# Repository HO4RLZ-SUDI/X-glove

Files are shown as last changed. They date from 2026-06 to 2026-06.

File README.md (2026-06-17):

# Glove Project

Smart glove project with Android BLE controls, ESP32 firmware, CAD case files,
and build notes.

## Folder layout

- `apps/android_ble_app` - Kotlin + Jetpack Compose Android app.
- `firmware/esp32_glove_ble` - main ESP32 BLE glove firmware.
- `firmware/esp32_ble_name_server` - BLE name server and OLED status sketch.
- `firmware/tests/oled_i2c_test` - OLED I2C test sketch.
- `hardware/cad` - OpenSCAD, STL, and 3MF case versions.
- `docs/bom_budget.ods` - parts budget and BOM spreadsheet.
- `up.sh` - firmware picker, compile, upload, and serial monitor helper.

## Common commands

List available Arduino sketches:

```bash
./up.sh --list
```

Build and upload firmware:

```bash
./up.sh
```

Build the Android app:

```bash
cd apps/android_ble_app
./gradlew assembleDebug
```

# X-glove

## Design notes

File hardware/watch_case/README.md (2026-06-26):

# Glove wrist unit — watch-style enclosure

A 3D-printable, two-part wrist case for the glove electronics, styled after the
reference `frame.stl` (an Apple-Watch-like squircle: ~43 × 49 mm face, rounded
"pillow" edges, side crown + button). The reference is a solid styling shell —
this is the functional version: hollow, holds the boards, and has a display
window, USB access, and a flex-cable entry.

The body is built as a squircle prism **Minkowski-rounded by a sphere**, so every
outer edge (top, back, vertical corners) is filleted into one smooth pillow like
the reference, while the side walls stay flat and the shell stays a uniform
thickness. The face is a flat, recessed **rounded-rectangle "glass" area** (no
cosmetic round ring) with the OLED window in it — Apple-Watch style.

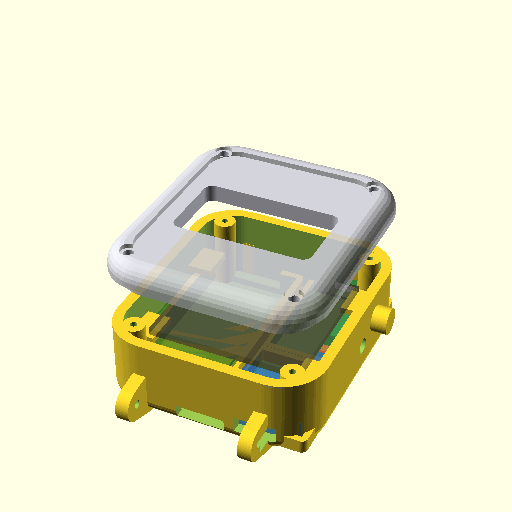
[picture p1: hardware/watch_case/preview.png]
preview


## What it fits

| Part | Size used | Where |
| --- | --- | --- |
| SH1106 1.3" OLED (128×64) | board 35×33, active 29×15.5 | top, behind the window |
| ESP32-C3 SuperMini | 22.5×18×6, USB-C on short end | board slot, +X column −Y end, USB to −Y wall |
| Type-C charge module | TP4056-class 26×17×5, USB-C on short end | board slot, +X column +Y end, USB to +Y wall |
| MPU6050 (GY-521) | 16×21×3 | shelf over the charge module (floor is full; still rigid) |
| LiPo pouch | **20×40×6** | walled compartment on the −X floor, wired to the charge module |
| Flex-divider board | thin perfboard ~22×40×≤2.5 | rests on the battery compartment walls (holds the 5 pull-down resistors) |
| Flex-sensor ribbon | ~11×3 slot | −Y wall centre (palm side) |

Wrist band: **Apple-Watch-style lugs** with a quick-release spring-bar channel
(default 24 mm / 42-45-49 family — see Assembly step 7).

**Power path:** the LiPo is wired to the on-board **Type-C charge module**, so the
case charges through the +Y wall port without opening it; the ESP32's own USB-C
(−Y wall) is then only for flashing. (No `BATTERY_PIN` is free on the C3 — all of
ADC1 goes to the 5 flex channels — so battery % isn't read in firmware.)

The footprint grew from the reference's 43 × 49 mm to **48 × 55 mm** so the LiPo
compartment (−X) sits beside the ESP32 + charge module column (+X) on a single
floor layer. **Thickness is 23 mm, not the reference's 14.4 mm:** the stack is
floor → 6 mm LiPo (in its compartment) +
ESP32 / charge module on the floor → a thin flex-divider perfboard (over the
battery) and the MPU (over the charge module) → the 1.3" OLED at the lid. The
LiPo, ESP32 and charge module are a single floor layer; only the thin perfboard
and the MPU stack. The pillow form (rounded
edges) makes it *read* much thinner than a flat-topped box of the same height. To
get closer to the reference profile, use a 0.96" OLED and set `case_h = 16`.

### Why a perfboard, not a real breadboard
The wiring junction (the 5 flex pull-down resistors + the ribbon/I2C/ESP meeting
point) is the only thing that actually needs a board — **9 nets total**: `3V3`,
`GND`, `SDA`/`SCL`, and `F1..F5`. An 8-column slice of an SYB-170 mini-breadboard
(5 resistor columns + 3 bus columns ≈ 22 × 35 mm) is enough *electrically*, but a
breadboard is **8.5 mm tall** and will not fit under the 1.3" OLED without pushing
the case to ~27 mm. So the bay is sized for a **thin perfboard (≤ 2.5 mm)** or a
breadboard with its leads cropped flush. Tune with `bb_t`; raise `case_h` and
`bb_z` if you insist on a full-height breadboard.

## Files

- `watch_case.scad` — the parametric source (edit the variables at the top).
- `base.stl`, `lid.stl` — ready-to-slice parts (regenerate after editing).
- `preview.png`, `section.png` — renders.

## Render / export

```bash
openscad -o base.stl -D 'part="base"' watch_case.scad
openscad -o lid.stl  -D 'part="lid"'  watch_case.scad
# previews:
openscad -o preview.png --viewall --autocenter watch_case.scad            # exploded + ghost parts
openscad -o section.png -D 'part="section"' --viewall --autocenter watch_case.scad
```

`part` accepts `base`, `lid`, `preview` (default, lid lifted off with translucent
component placeholders), or `section` (cutaway).

## Key parameters (top of `watch_case.scad`)

| Var | Default | Meaning |
| --- | --- | --- |
| `W`, `L`, `case_h` | 48, 55, 22 | outer width / length / thickness (mm) |
| `batt_w`, `batt_l`, `batt_t` | 20, 40, 6 | LiPo compartment W×L×depth (mm) |
| `batt_rib`, `batt_clr` | 1.6, 0.4 | compartment wall thickness / cell slip clearance |
| `esp_w`, `esp_l`, `esp_t` | 18, 22.5, 6 | ESP32-C3 board slot W×L×H (mm) |
| `chg_w`, `chg_l`, `chg_t` | 17, 26, 5 | Type-C charge module bay W×L×H (mm) |
| `bb_w`, `bb_l`, `bb_t`, `bb_z` | 22, 40, 2.0, — | flex-divider board footprint / thickness / shelf height |
| `corner_r` | 10 | squircle vertical corner radius |
| `edge_r` | 4.0 | 3D fillet on all outer edges (the pillow roundness) |
| `lid_cap` | 5.0 | height of the domed top cap = the lid |
| `wall`, `floor_th`, `lid_th` | 2.4, 2.0, 2.0 | shell thicknesses |
| `fit_gap` | 0.25 | lid↔base print clearance — widen if the lid is tight |
| `oled_*`, `esp_*`, `mpu_*`, `batt_*` | — | component sizes; edit to your exact parts |
| `aw_large`, `band_w` | true, 24 | Apple band size: true=42/44/45/49 (24mm), false=38/40/41 (20mm) |
| `bar_d`, `bar_z` | 1.9, 6.0 | spring-bar hole dia / height above the back |
| `crown_d`, `btn_d` | 6, 3.6 | cosmetic crown / button-access hole |

Everything downstream (ledge heights, window, screw bosses, lugs) is derived, so
changing a component size re-fits the case automatically.

## Assembly

1. **LiPo** drops into the walled −X compartment (20×40×6; thumb-scoop on the +Y
   end to lift it out). Its leads run to the **charge module**.
2. **ESP32-C3** slots into the +X column, −Y end (USB-C faces the −Y wall, for
   flashing). **Charge module** slots into the +X column, +Y end (USB-C faces the
   +Y wall — this is the charge port). **MPU6050** glues flat onto the charge
   module, pressed rigid — any play shows up as accel/gyro noise.
3. **Flex-divider board** drops in flat onto the battery compartment walls (no
   posts). Land the five pull-downs here (one per finger, node→GND across the
   board), the incoming ribbon (`F1..F5` + `3V3`), and short jumpers to the
   ESP32's `GPIO0..4`, `3V3`, `GND`, plus the shared I2C bus (`SDA`=G5, `SCL`=G6)
   out to the OLED and MPU. 9 nets total. Keep it ≤ 2.5 mm thick (perfboard, or a
   breadboard with the leads cropped flush) or it fouls the OLED.
4. **OLED** rests on the four wall tabs (high on the ±X walls, clear of the
   boards), glass just under the window.
5. Route the flex ribbon in through the −Y (palm-side) slot to the divider board.
6. Drop the **lid** in (lip aligns it) and fix with 4× M2 self-tapping screws
   into the corner bosses; heads countersink flush on top.
7. **Band:** the lugs are Apple-Watch style with a through spring-bar channel.
   Use an Apple-Watch band that has **quick-release pins**, or a cheap
   "Apple Watch → spring bar" adapter for Apple's first-party slide-lock bands.
   Default gap is 24 mm (42/44/45/49 family); set `aw_large = false` for the
   38/40/41 (20 mm) family. Apple's native metal slide-lock is intentionally not
   reproduced — it needs the band's spring mechanism and won't print reliably.
   Tune `band_w` / `bar_z` to your physical band and reprint just one end with
   `-D 'part="base"'` cropped, or do a quick caliper check before the full print.

## Print notes

- Base prints open-side up (no supports). Lid prints face-down (glass side on the
  bed) so the flat recessed face comes out clean; the rounded top then needs no
  supports and the countersinks self-support.
- PETG/ABS for a wearable that flexes; PLA is fine for a prototype.
- Both STLs verified watertight (0 non-manifold edges, single connected solid).

## Deviations from the reference (on purpose)

- **Bigger** (48 × 55 × 22 vs 43 × 49 × 14.4 mm) to hold real components on a
  single floor layer (LiPo + ESP32 + charge module) — see above. The pillow
  edges keep it looking watch-like despite the height.
- **Flat rectangular glass face** instead of the reference's round front boss:
  the SH1106 is rectangular, so the face is a recessed rounded-rect "screen" with
  the OLED window in it. Switch to a round GC9A01 display for a fully round face
  (needs a firmware driver change away from U8G2/SH1106).
- **Crown is cosmetic**; the rectangular side hole is the functional button
  (wire it to EN/reset or a GPIO as you like).

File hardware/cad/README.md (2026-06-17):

# CAD Versions

All dimensions are in millimeters.

## v4_comfy

Recommended current version.

- `esp32c3_oled_case_comfy_layout.3mf` - print-ready layout with case, lid, and glove mount separated
- `esp32c3_oled_case_comfy_assembly.3mf` - assembled preview
- `esp32c3_oled_case_comfy.scad` - editable OpenSCAD source
- `*_case.stl`, `*_lid.stl`, `*_mount.stl` - individual printable parts

A usability pass over `v3_usable` aimed at being easier to print, open, wear, and
service:

- **One `fit` knob** at the top of the .scad feeds every press/slide clearance
  (lid lip, case-in-mount rails, snap latch). Print a test case + lid, then nudge
  `fit` by 0.05 mm if anything binds or feels loose. Default is 0.10 mm.
- **Easier to open:** `lid_screw_count = 2` keeps only the diagonal screw pair
  (the alignment tabs and rear snap latch hold the other corners); set it to 4 to
  fully lock. A fingernail pry scoop (`lid_pry_recess`) on the front lid edge pops
  the lid by hand.
- **Smaller / comfier:** the glove mount plate is slimmer (62 x 48 x 2.35 mm vs
  68 x 52 x 2.7) with softer 10 mm corners for a lower profile on the hand.
- **Port/button access:** a `tool_hole` pin port through the lid reaches the
  board's BOOT/RESET button without opening the case. It defaults over the front
  of the board, clear of the OLED — verify `tool_hole_x/_y` against your module,
  or set `tool_hole = false` to remove it.

All four behaviours are parameters at the top of the source, so anything can be
dialled back to the v3 geometry.

## v3_usable

Previous recommended version.

- `esp32c3_oled_case_usable_layout.3mf` - print-ready layout with case, lid, and glove mount separated
- `esp32c3_oled_case_usable_assembly.3mf` - assembled preview
- `esp32c3_oled_case_usable.scad` - editable OpenSCAD source
- `*_case.stl`, `*_lid.stl`, `*_mount.stl` - individual printable parts

This version is a usability pass over `v2_masterpiece`: the case is slightly smaller, USB-C and wire exits have more clearance, the OLED lid pass-through is set for a top-center display connector, the glove mount plate is shorter and lower, screw bosses have support ribs, and the rear snap latch has a larger tactile release area. The two M2 mount screws can still be used as safety retainers for hard movement.

## v2_masterpiece

Older version.

- `esp32c3_oled_case_masterpiece_layout.3mf` - print-ready layout with case, lid, and glove mount separated
- `esp32c3_oled_case_masterpiece_assembly.3mf` - assembled preview
- `esp32c3_oled_case_masterpiece.scad` - editable OpenSCAD source
- `*_case.stl`, `*_lid.stl`, `*_mount.stl` - individual printable parts

This version includes a quick-lock glove mount: two front stops leave the USB-C port clear, and a rear snap latch engages a notch in the case.

## v1_oled_case

Earlier ESP32-C3 + OLED glove mount version.

- `esp32c3_oled_case_layout.3mf` - print-ready layout
- `esp32c3_oled_case_assembly.3mf` - assembled preview
- `esp32c3_oled_case.scad` - editable OpenSCAD source

## v0_xglove

Original wrist case version.

- `xglove.scad` - editable OpenSCAD source
- `xglove.3mf` - exported model

## legacy_wrist_3mf

Older exported 3MF files kept for reference only.

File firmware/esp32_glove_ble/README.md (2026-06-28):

# ESP32 BLE Glove Firmware (v2.2.0)

Arduino sketch for the Android app in this repo.

## BLE contract

- Service UUID: `0000FFE0-0000-1000-8000-00805F9B34FB`
- Characteristic UUID: `0000FFE1-0000-1000-8000-00805F9B34FB`
- Properties: Read, Write, Notify
- Negotiated MTU: 185 (the app requests the same) so a full packet fits one
  notification.
- Notify payload: `DATA:f1=...,f5=...,ax=...,ay=...,az=...,gx=...,gy=...,gz=...,b=...,n=...`
  - `f1..f5` = flex channels (always present, sent first)
  - `ax,ay,az` / `gx,gy,gz` = MPU6050 accel/gyro as **raw int16 counts**
    (default ranges: accel ±2 g = 16384 LSB/g, gyro ±250 °/s = 131 LSB/°/s).
    Omitted entirely when no IMU is present, so the app treats them as optional.
  - `b` = battery millivolts (omitted when battery monitoring is off)
  - `n` = packet sequence number
- Gesture notify payload: `GEST:<thai phrase>` — sent once when a bent-finger
  gesture is recognised (see [Gestures](#gestures)). Independent of `START`/`STOP`
  streaming. The same phrase is also printed to USB serial as `SAY:<thai phrase>`
  for the host `tests/flex_sensor_test/greet_bridge.py` TTS bridge.
- Commands written to `FFE1`:
  - `CAL`: stores the current flex readings as baseline.
  - `CAL:CLEAR` (or `RESETCAL`): clears the stored baseline.
  - `START`: starts live notifications.
  - `STOP`: stops live notifications.
  - `RATE:<ms>`: sets the telemetry interval (20-1000 ms, persisted).
  - `STATUS`: replies `OK:STATUS:s=<stream>,r=<rate>,b=<mv>,u=<uptime s>,p=<packets>,h=<L|R|->`
    (plus `,i=<imu present 0/1>` when the IMU is enabled,
    `,l=<oled brightness 0-100>` when the OLED is enabled, and
    `,g=<gesture count>`). `h` is the hand tag.
  - `CAL` also re-zeros the gesture detector (do it with the hand held flat).
  - `VER`: replies `OK:VER:<firmware version>`.
  - `PING`: replies `OK:PONG`.
  - `OLED:DASH`, `OLED:TELEM`, `OLED:SYS`, `OLED:HAND`, `OLED:WAVE`: switches
    the OLED display page.
  - `OLED:NEXT`: cycles to the next OLED display page.
  - `BRIGHT:<0-100>`: sets the OLED brightness/contrast (persisted).
  - `NAME:<name>` (up to 20 chars): saves the BLE device name. This is the only
    way to rename the glove — any other unrecognized write replies
    `ERR:UNKNOWN_COMMAND` (a typo'd command can no longer silently rename it).
  - `HAND:L` / `HAND:R`: tags this glove as the left or right hand (persisted),
    and appends `-L` / `-R` to the advertised name so the dual-hand app assigns
    the correct slot automatically. `HAND:CLEAR` removes the tag. Like `NAME:`,
    the advertised name changes on the next boot; replies `OK:HAND:<L|R>` or
    `OK:HAND:CLEAR` (and `ERR:BAD_HAND` for anything else).

Commands received over BLE are queued and executed from `loop()`, so slow work
(calibration animation, NVS writes) never blocks the BLE stack thread. If a
command arrives while another is still queued, the firmware replies `ERR:BUSY`.

## Gestures

The firmware decides per finger whether it is bent (with hysteresis) and turns
the five bend states into a 5-bit pattern. Holding a known pattern steady
(~300 ms) fires its phrase once over BLE (`GEST:<phrase>`) and serial
(`SAY:<phrase>`); relax to flat (or form another combo) to fire again. A
flat-hand reference is captured on boot and on every `CAL` — keep the hand flat
for both.

Detection runs continuously, even with no BLE client connected (so the USB
serial → `greet_bridge.py` TTS path works standalone). The `GESTURES[]` table
here is kept in sync with
[`../tests/flex_sensor_test/README.md`](../tests/flex_sensor_test/README.md),
which has the live-tuning notes.

The 10 most-useful phrases, each on an easy 1–2 finger (or full-fist) combo.
Finger codes **1**=thumb, **2**=index, **3**=middle, **4**=ring, **5**=pinky.
Bend the listed fingers and hold:

| Fingers | Phrase | English | |
|---|---|---|---|
| 1 2 3 4 5 | ช่วยด้วย | help | (fist) |
| 1 2 | เจ็บ | hurt | |
| 2 | ใช่ | yes | |
| 2 3 | ไม่ใช่ | no | |
| 1 | หิวข้าว | hungry | |
| 5 | ต้องการน้ำ | need water | |
| 4 5 | เข้าห้องน้ำ | bathroom | |
| 1 5 | สวัสดี | hello | |
| 2 3 4 5 | ขอบคุณ | thank you | |
| 2 3 4 | ไม่สบาย | sick | |

Tuning constants near the top of the sketch: `GESTURE_BEND_ON` (200),
`GESTURE_BEND_OFF` (120), `GESTURE_SETTLE_MS` (300), `GESTURE_SAMPLE_MS` (40).

## Signal quality

- Flex readings are smoothed with an exponential moving average
  (`FLEX_EMA_ALPHA`, default 0.45) on top of 8-sample averaging.
- Battery voltage uses `analogReadMilliVolts` (factory ADC calibration) and is
  cached for 2 seconds to keep the telemetry loop fast.

The app updates the connected name immediately after `OK:<name>`. The ESP32
advertised name uses the saved value after the board restarts.

## Default Pins (ESP32-C3 SuperMini)

- Flex sensors: GPIO `0`, `1`, `2`, `3`, `4` (ADC1 — the only ADC channels on C3)
- Battery ADC: disabled (`-1`); GPIO0..4 are all used by the flex sensors
- Shared I2C bus (OLED + MPU6050): SDA GPIO `5`, SCL GPIO `6`

Edit these constants at the top of `esp32_glove_ble.ino` to match your wiring:

```cpp
static const int FLEX_PINS[] = {0, 1, 2, 3, 4};
static const int BATTERY_PIN = -1;
static const float BATTERY_DIVIDER_RATIO = 2.0f;
static const int I2C_SDA_PIN = 5;
static const int I2C_SCL_PIN = 6;
```

Set `BATTERY_PIN` to a free ADC pin to enable battery monitoring.

> **GPIO2 warning:** GPIO2 is a boot strapping pin on the ESP32-C3 and must not
> be held LOW at power-on, or the board may fail to boot / enter download mode.
> Wire that flex channel so the pin rests HIGH at boot. Fully removing the risk
> means dropping to 4 flex channels or moving the I2C bus to free a
> non-strapping ADC pin — both are wiring decisions, not firmware ones.

## IMU (MPU6050)

An MPU6050 accel/gyro shares the I2C bus with the OLED (same SDA/SCL). The
firmware auto-detects it at `0x68`/`0x69`, wakes it, and streams raw accel/gyro
counts in every `DATA:` packet. It is enabled by default; disable with:

```cpp
#define GLOVE_ENABLE_IMU 0
```

No extra library is needed — the sketch talks to the MPU6050 over `Wire`
directly. If the IMU is absent or fails to init, BLE keeps running and the IMU
fields are simply omitted from the packet. On long/thin glove wiring, if IMU
reads are flaky, lower `I2C_CLOCK_HZ` (the MPU6050 tops out at 400 kHz).

## OLED display

The firmware supports a 128x64 I2C DST-013 / SH1106 OLED display. It shows a
short boot animation, then one of five app-selectable pages:

- `Dashboard`: saved BLE name, BLE icon, streaming icon, battery icon, and flex
  sensor bar graphs.
- `Telemetry`: large flex spectrum bars and battery percentage.
- `System`: device name, BLE state, streaming state + rate, packet count,
  uptime, battery voltage, and firmware version.
- `Hand`: a hand drawing whose fingers shorten as each flex sensor bends.
- `Waveform`: scrolling history graph for all five flex channels.

The display refreshes at 250 ms while streaming to a connected app and 500 ms
otherwise. When the battery drops below 15%, a blinking `LOW BATT` banner is
drawn over every page. After 25 s without a connection the screensaver starts.

Install these Arduino libraries before compiling with OLED enabled:

- `U8g2`

OLED support is enabled by default. To disable it, change this macro near the
top of `esp32_glove_ble.ino`:

```cpp
#define GLOVE_ENABLE_OLED 0
```

The OLED shares the I2C pins above (`I2C_SDA_PIN` / `I2C_SCL_PIN`). If your
display uses a different address, edit this constant:

```cpp
static const uint8_t OLED_I2C_ADDRESS = 0x3C;
```

For a different controller or screen size, change the U8g2 driver class in the
sketch. The DST-013 is configured as `U8G2_SH1106_128X64_NONAME_F_HW_I2C`.

If no OLED is connected or initialization fails, the firmware continues running
BLE normally.

## Upload

The easiest way is the repo's `up.sh` helper (auto-detects the port, this
firmware is choice 1 / the Enter default):

```bash
./up.sh                 # pick firmware, compile, upload
./up.sh --monitor       # same, then open the serial monitor
./up.sh --monitor-only  # just watch serial output
```

In Arduino IDE, install/select an ESP32 board package, open
`esp32_glove_ble.ino`, choose your ESP32 board and port, then Upload.

With `arduino-cli`, the command usually looks like:

```bash
arduino-cli compile --fqbn esp32:esp32:esp32 firmware/esp32_glove_ble
arduino-cli upload -p /dev/ttyUSB0 --fqbn esp32:esp32:esp32 firmware/esp32_glove_ble
```

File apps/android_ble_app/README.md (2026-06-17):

# Glove BLE Android App

Kotlin + Jetpack Compose app for scanning, connecting, monitoring, and sending
commands to an ESP32-based BLE glove.

## BLE contract

- Service UUID: `0000FFE0-0000-1000-8000-00805F9B34FB`
- Name Characteristic UUID: `0000FFE1-0000-1000-8000-00805F9B34FB`
- Characteristic properties: Read, Write, Notify
- The app scans devices whose advertised name starts with `ESP32`, `Glove`,
  `SmartGlove`, or `BLEGlove`, or whose advertising data contains the service UUID.
- Notifications on `FFE1` are shown as live glove data when the payload starts
  with `DATA:`, `SENSOR:`, `FLEX:`, `IMU:`, or looks like numeric telemetry
  such as `f1=123,f2=456` or `123,456,789`.
- Live packets carry five flex channels plus optional MPU6050 accel/gyro
  (`ax,ay,az,gx,gy,gz`, raw int16 counts). The Live screen shows accel in g and
  gyro in °/s; the IMU section is hidden when no IMU data arrives.
- Device renames are sent as `NAME:<name>` (the firmware rejects other
  unrecognized writes with `ERR:UNKNOWN_COMMAND`). Acknowledgements use
  `OK:<name>` or `ERR:<reason>`.
- The app requests a 185-byte MTU so a full flex + IMU packet fits one
  notification.
- The command box writes UTF-8 commands to `FFE1`; quick commands are `CAL`,
  `START`, and `STOP`.
- The connected screen includes an OLED page selector. It sends `OLED:DASH`,
  `OLED:TELEM`, `OLED:SYS`, `OLED:HAND`, or `OLED:WAVE` to switch the glove
  display page.
- Recorded gesture sessions are saved to `gestures.csv`
  (`label,session,t_ms,f1..f5,ax,ay,az,gx,gy,gz`; older 8-column files without
  IMU still load) and can be reviewed in the dataset viewer with 5-channel
  waveform playback.

## Build

Open `apps/android_ble_app` in Android Studio, or build from the repo root:

```bash
cd apps/android_ble_app
./gradlew assembleDebug
```

If Gradle cannot find the Android SDK on this machine, update `local.properties`.

## Run

```bash
adb install -r app/build/outputs/apk/debug/app-debug.apk
```

Android 12+ requires Bluetooth Scan and Connect permissions. Android 11 and older require Location permission for BLE scanning.

## Firmware

ESP32 Arduino firmware is in `firmware/esp32_glove_ble`.

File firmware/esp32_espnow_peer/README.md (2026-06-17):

# esp32_espnow_peer

Two-way [ESP-NOW](https://docs.espressif.com/projects/esp-idf/en/latest/esp32c3/api-reference/network/esp_now.html)
link between two ESP32-C3 boards. No Wi-Fi router or IP setup needed — boards
talk directly using each other's MAC address.

## Steps

1. **Get each board's MAC.** Flash `../esp32_espnow_mac` to each board and read
   the STA MAC from the serial monitor (115200 baud). Note both, e.g.
   - Board A: `AA:BB:CC:11:22:33`
   - Board B: `AA:BB:CC:44:55:66`

2. **Set `BOARD_A` / `BOARD_B`.** In `esp32_espnow_peer.ino`, fill in both
   MACs. At boot each board reads its own MAC and picks the other as its peer,
   so you flash the *same* sketch to both — no per-board edits.

3. **Flash both boards** with this sketch and open both serial monitors. Each
   sends a counter packet every 2s and prints what it receives.

## OLED status display

If a board has an SH1106 128x64 OLED on I2C (SDA=5, SCL=6), it shows the link
status: `LINK UP` / `NO LINK`, peer's last two MAC bytes, RSSI, TX ok/total
counts, and the last received id/value. Boards without a display run headless.

## Troubleshooting `send -> FAIL`

ESP-NOW unicast reports OK only when the peer ACKs at the MAC layer, so:

- **Both boards must be powered and flashed.** A single board talking to a
  missing peer fails every send.
- **Same channel.** This sketch pins both radios to `WIFI_CHANNEL` (1) via
  `esp_wifi_set_channel`.
- **Modem sleep.** STA mode sleeps the radio by default, so the receiver may
  miss the packet and never ACK. The sketch disables it with
  `WiFi.setSleep(false)` / `esp_wifi_set_ps(WIFI_PS_NONE)`.
- **Range / power.** Place the boards close together while testing.

## Notes

- Board: select **ESP32C3 Dev Module** in Arduino IDE.
- The `struct_message` layout must be identical on both boards.
- Built for ESP32 Arduino core **v3.x** (v3.3+ callback signatures
  `wifi_tx_info_t` / `esp_now_recv_info_t`).
- For a secure link, set `peer.encrypt = true` and configure a PMK/LMK.

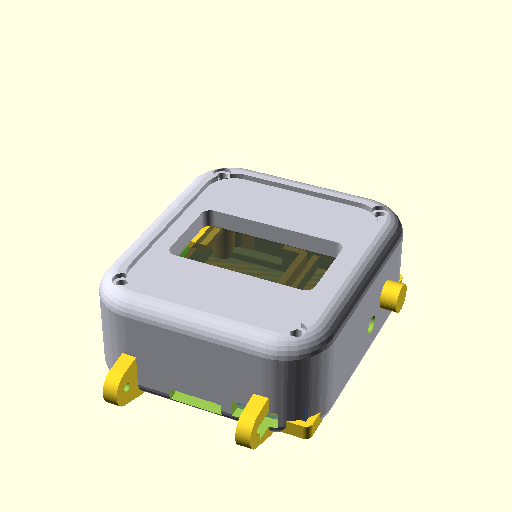
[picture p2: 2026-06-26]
hardware/watch_case/section.png

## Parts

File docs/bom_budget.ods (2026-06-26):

Name | Price | Amout ( p ) | total
ESP32-C3 | 100 | 2 | 200
Mpu6050 | 54 | 2 | 108
flex sensor | 180 | 12 | 2160
ถุงมือ | 85 | 2 | 170 | ยอดสุทธิ | คงเหลือ
แบตเตอรี่ | 70 | 2 | 140 | 2778 | 722

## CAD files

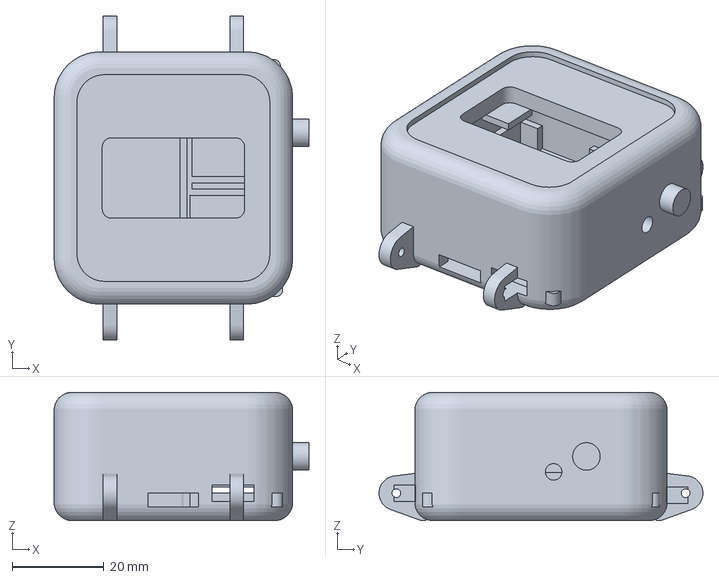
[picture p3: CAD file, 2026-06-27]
hardware/watch_case/full.3mf
55.5 x 70.6 x 28.0 mm

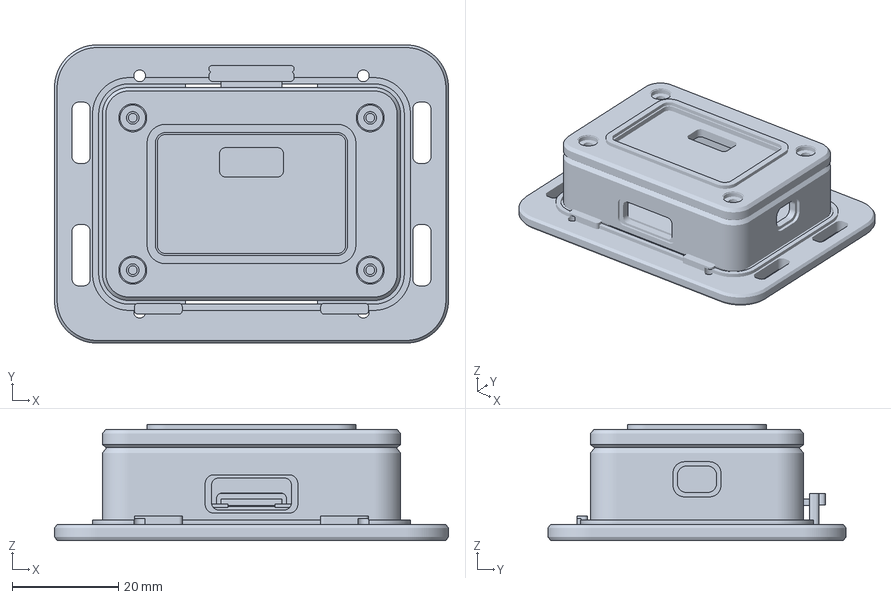
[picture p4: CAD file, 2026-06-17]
hardware/cad/v2_masterpiece/esp32c3_oled_case_masterpiece_assembly.3mf
74.0 x 56.0 x 21.8 mm

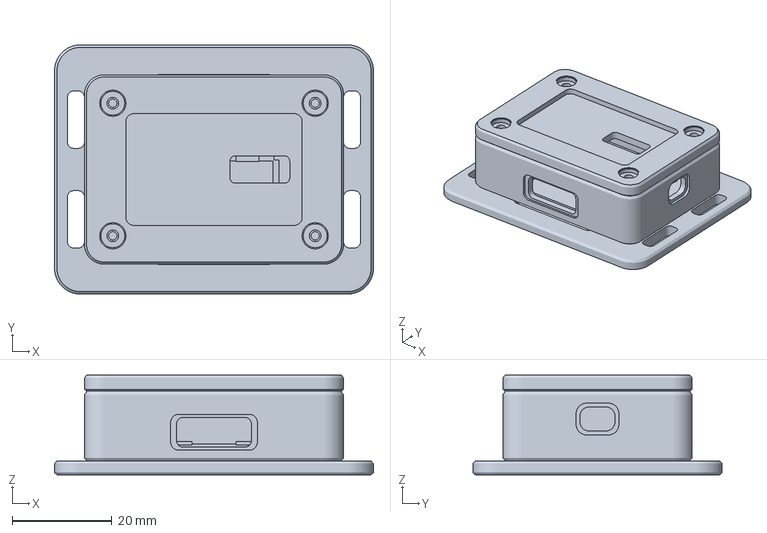
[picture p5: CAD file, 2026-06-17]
hardware/cad/v1_oled_case/esp32c3_oled_case_assembly.3mf
64.0 x 50.0 x 20.0 mm

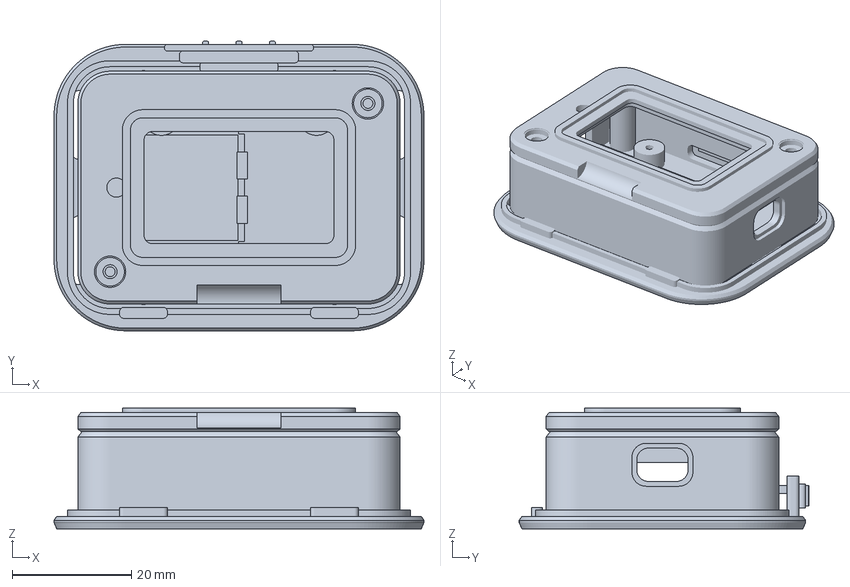
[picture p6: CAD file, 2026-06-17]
hardware/cad/v4_comfy/esp32c3_oled_case_comfy_assembly.3mf
62.0 x 48.5 x 20.2 mm

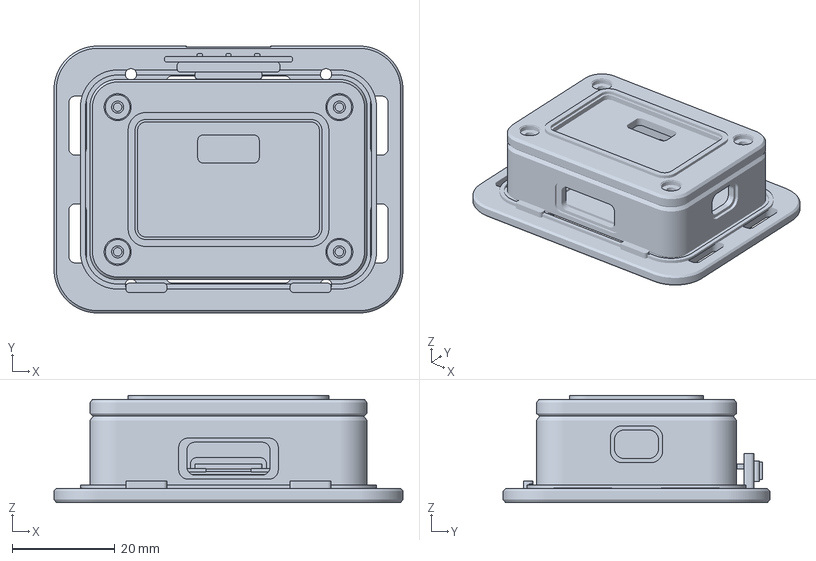
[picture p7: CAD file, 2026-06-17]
hardware/cad/v3_usable/esp32c3_oled_case_usable_assembly.3mf
68.0 x 52.0 x 20.8 mm

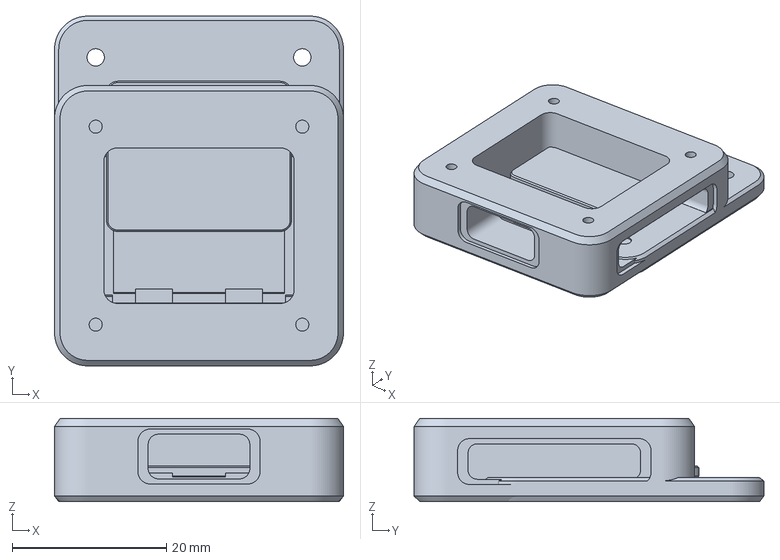
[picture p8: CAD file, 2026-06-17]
hardware/cad/v0_xglove/xglove.3mf
37.5 x 45.4 x 10.8 mm

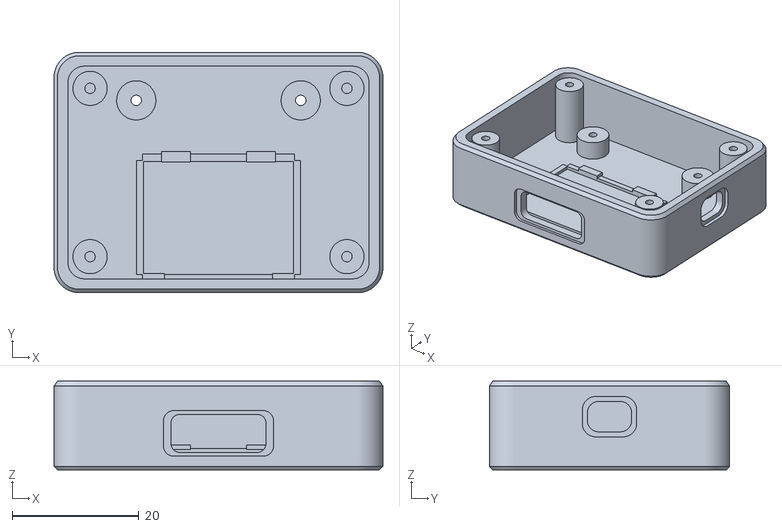
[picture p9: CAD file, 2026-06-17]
hardware/cad/v1_oled_case/esp32c3_oled_case_case.stl
52.0 x 38.0 x 14.0

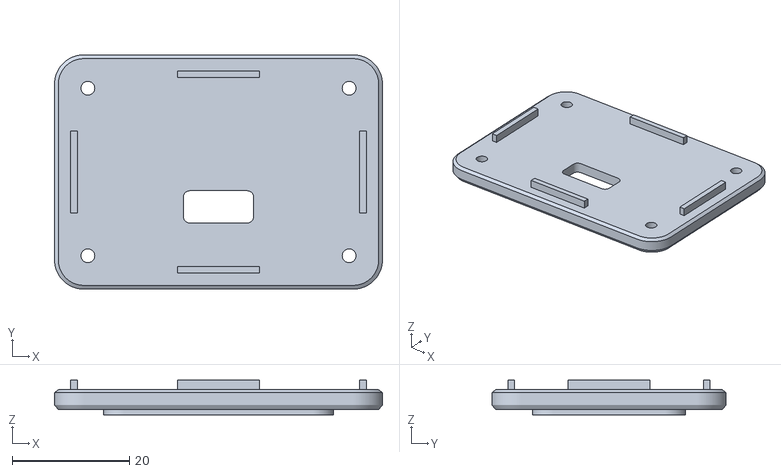
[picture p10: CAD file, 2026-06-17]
hardware/cad/v2_masterpiece/esp32c3_oled_case_masterpiece_lid.stl
56.0 x 40.0 x 5.95

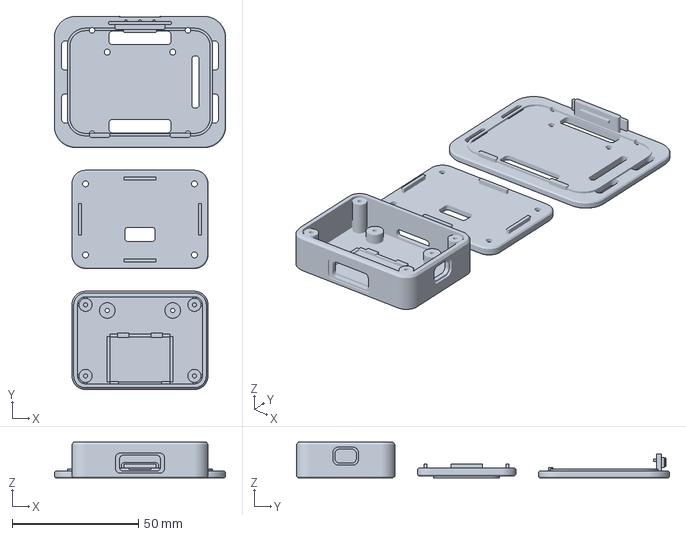
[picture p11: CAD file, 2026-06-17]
hardware/cad/v3_usable/esp32c3_oled_case_usable_layout.3mf
68.0 x 148.0 x 14.2 mm

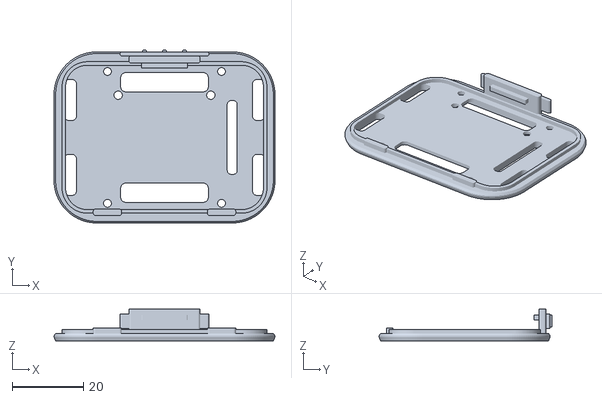
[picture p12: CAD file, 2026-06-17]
hardware/cad/v4_comfy/esp32c3_oled_case_comfy_mount.stl
62.0 x 48.5 x 8.90

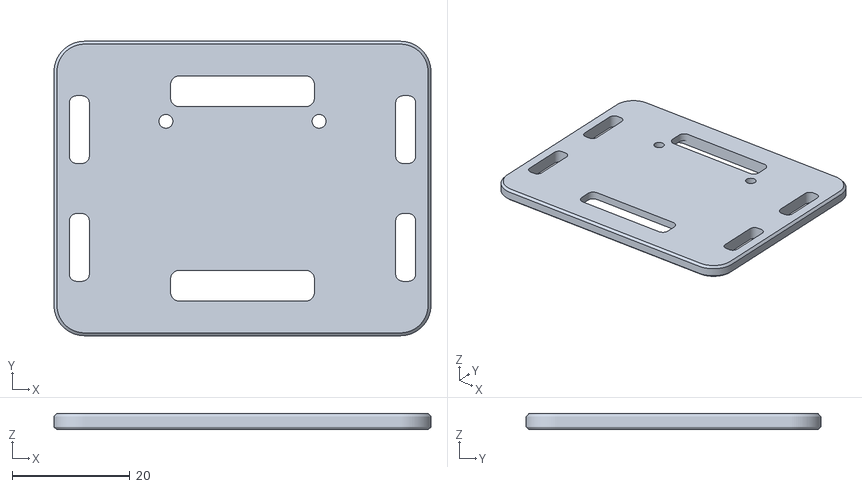
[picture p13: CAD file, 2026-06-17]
hardware/cad/v1_oled_case/esp32c3_oled_case_mount.stl
64.0 x 50.0 x 2.80

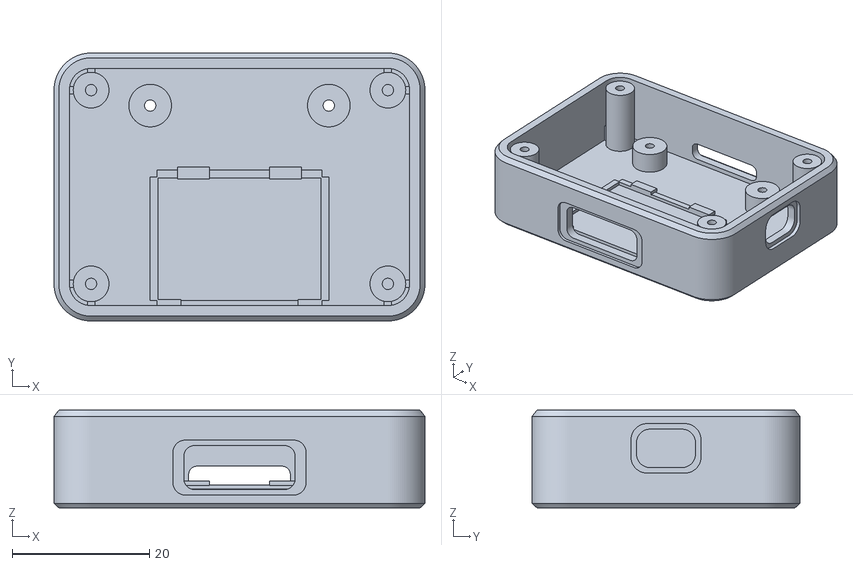
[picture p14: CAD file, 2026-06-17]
hardware/cad/v3_usable/esp32c3_oled_case_usable_case.stl
54.0 x 39.0 x 14.2

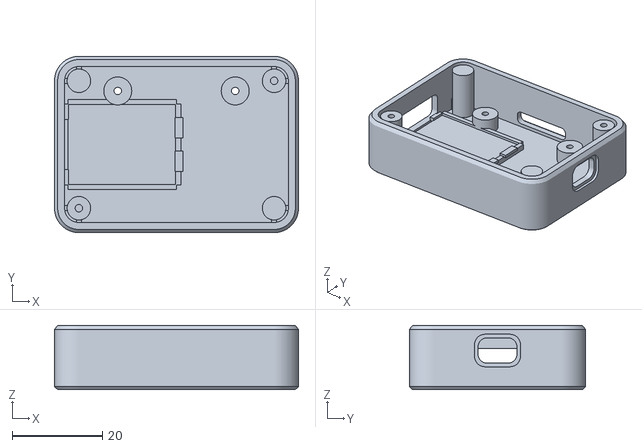
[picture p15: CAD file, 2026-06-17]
hardware/cad/v4_comfy/esp32c3_oled_case_comfy_case.stl
54.0 x 39.0 x 14.2

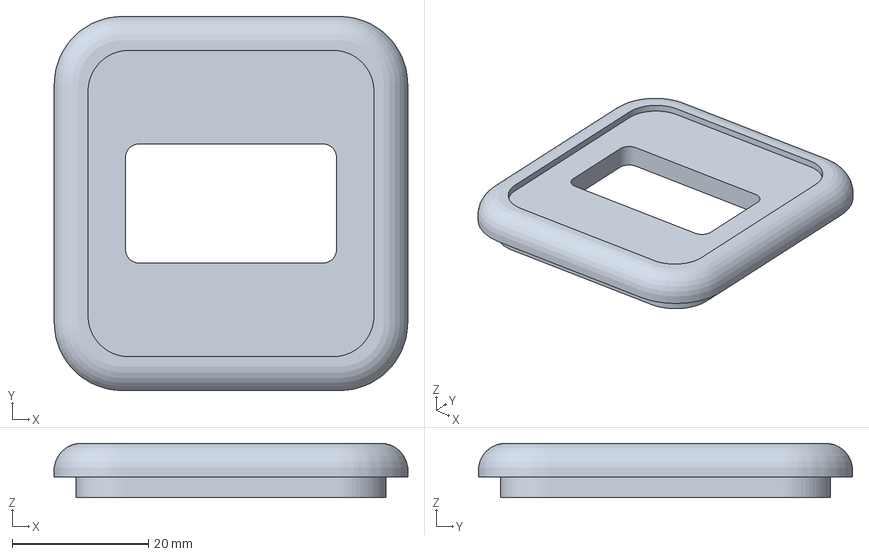
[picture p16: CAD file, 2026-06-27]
hardware/watch_case/lid.3mf
51.9 x 54.9 x 7.97 mm

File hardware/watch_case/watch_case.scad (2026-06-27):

// ============================================================================
// Glove wrist unit — watch-style enclosure
// Reference: ~/Downloads/frame.stl (Apple-Watch-like squircle, 43 x 49 x 14.4mm,
// round face boss + side crown/button). This keeps that silhouette but makes a
// functional two-part case for the glove electronics:
//   - SH1106 1.3" 128x64 OLED (U8G2 driver in firmware)
//   - ESP32-C3 SuperMini   (USB-C on a side wall for charge/flash)
//   - MPU6050 (GY-521)     (rigidly mounted so accel/gyro tracks the wrist)
//   - 502535 LiPo (~5 x 25 x 35 mm)
//   - flex-sensor ribbon exits the palm-side (-Y) end
//
// The reference is 14.4mm thick (a solid styling shell). A real 1.3" OLED + MCU
// + battery stack needs ~20mm, so footprint matches the ref and thickness is a
// parameter (case_h). Drop a 0.96" OLED / thinner battery to slim it down.
//
// Render:  openscad -o base.stl -D 'part="base"' watch_case.scad
//          openscad -o lid.stl  -D 'part="lid"'  watch_case.scad
// ============================================================================

part = "preview";          // "base" | "lid" | "preview" | "section"
$fn = 64;

// ---- Outer shell (squircle "pillow" form, like the reference) -------------
W          = 52;           // width  (X)  — grown from ref 43.4 to floor the LiPo
                           // compartment (-X) beside the ESP32 + charge module (+X)
L          = 55;           // length (Y)  — grown from ref 49.0 so the +X column fits
                           // the ESP32 and the Type-C charge module end-to-end
case_h     = 28;           // thickness (Z). Ref is 14.4 (a solid styling shell);
                           // raised to hold the 6mm LiPo + ESP32-C3 + 1.3" OLED +
                           // a thin flex-divider perfboard stacked over the battery.
                           // The pillow form makes it read thinner than a box.
                           // Drop to ~16 with 302030 + 0.96" and no perfboard.
corner_r   = 10;           // squircle corner radius (ref ~10)

// Pillow profile (this is the redesign — replaces the old flat-top box):
// the body is a squircle prism Minkowski-rounded by a sphere, so every edge
// (top, back, and the vertical corners) is filleted into one smooth "pillow"
// like the reference — with flat vertical side walls (clean, uniform shell).
edge_r     = 4.0;          // 3D fillet radius on all outer edges (the pillow)
lid_cap    = 5.0;          // height of the top cap = the lid (carries the glass)

wall       = 3.0;          // side wall thickness (thinnest at mid; thicker at top)
floor_th   = 3.0;          // base floor
lid_th     = 3.0;          // lid solid-plate thickness under the glass
fit_gap    = 0.25;         // print clearance between lid and base rebate

// The lid is the whole domed cap; base is the tub up to here.
parting_z  = case_h - lid_cap;

// ---- Components (edit to your exact parts) --------------------------------
// SH1106 1.3" module: board ~35x33, active area ~29x15, glass+parts ~3mm tall.
oled_pcb_w = 35; oled_pcb_l = 33; oled_pcb_t = 1.6;
oled_act_w = 29; oled_act_l = 15.5;   // visible glass -> window size + margin
oled_stack = 3.2;                     // glass/ribbon height above the PCB

// ESP32-C3 SuperMini ~22.5 x 18 x 6 (with parts), USB-C on a short end.
esp_w = 18; esp_l = 22.5; esp_t = 6;
usb_w = 9.2; usb_h = 3.6;             // USB-C cutout in the side wall
esp_rib = 1.4;                        // retaining-rail thickness around the board

// Type-C charge module (TP4056-USB-C class) ~26 x 17 x 5, USB-C on a short end.
// The LiPo is already wired to this module; it charges through the case wall.
chg_w = 17; chg_l = 26; chg_t = 5;
chg_rib = 1.4;
chgusb_w = 9.2; chgusb_h = 3.6;       // USB-C cutout for the charge module

// MPU6050 GY-521 ~21 x 16 x 3. Mounted 16(X) x 21(Y) on a shelf over the charge
// module (floor is full); still rigid to the case so it tracks the wrist.
mpu_w = 16; mpu_l = 21; mpu_t = 3;

// LiPo pouch — user-specified compartment 22(W) x 40(L) x 7.5(H) mm.
batt_w = 22; batt_l = 40; batt_t = 7.5;
batt_rib  = 1.6;           // retaining-wall thickness around the LiPo pocket
batt_clr  = 0.4;           // slip clearance so the cell drops in
// Pocket hugs the -X inner wall; +X column holds the ESP32 + charge module.
batt_cx   = -(W/2 - wall - batt_rib - batt_w/2 - batt_clr);

// ---- Floor layout (everything single-layer; W/L grown to make it fit) ------
// -X column = battery (batt_cx, above). +X column = ESP32 (-Y end) + charge (+Y).
esp_cx = batt_cx + batt_w/2 + batt_clr + batt_rib + 1 + esp_w/2;  // +X column centre
esp_cy = -(L/2 - wall - esp_l/2 - 0.5);                            // -Y end
chg_cx = esp_cx;
chg_cy =  (L/2 - wall - chg_l/2 - 0.5);                            // +Y end
mpu_z  = floor_th + chg_t + 0.6;                                   // MPU shelf over charge

// ---- Flex-divider junction board (the "breadboard") -----------------------
// Holds the 5 flex pull-down resistors + the ribbon/I2C/ESP junction. A real
// SYB-170 mini-breadboard is 8.5mm tall and will NOT fit under the 1.3" OLED
// here; cut it (or use perfboard) to ~22 x 40 and keep it THIN. It rests flat on
// the battery compartment walls (no posts — they fouled the ESP32 slot), under
// the OLED.  8 columns of SYB-170 = 5 resistor cols + 3 bus cols.
bb_w   = 22; bb_l = 40;    // cut board footprint (X x Y) — sits over the battery
bb_t   = 2.0;              // board thickness (perfboard ~1.6-2; breadboard 8.5)
bb_z    = floor_th + batt_t;   // rests on the battery wall top (~8mm); board top
                               // ~10mm stays under the 1.3" OLED PCB (~11.7mm)

// ---- Side features (crown + button, like the reference) -------------------
crown_d = 6;  crown_len = 3.5;        // cosmetic crown on +X side
btn_d   = 3.6;                        // tactile button access hole on +X side

// ---- Wrist band: Apple-Watch-style lugs -----------------------------------
// Two integrated lugs per end that hug the body like an Apple Watch, with a
// through quick-release spring-bar channel. Use an Apple-Watch band that has
// quick-release pins, or a cheap "Apple Watch -> spring bar" adapter for Apple's
// first-party slide-lock bands. Tune band_w / bar_z to your physical band.
aw_large   = true;                    // 42/44/45/49 band (true) vs 38/40/41 (false)
band_w     = aw_large ? 24.0 : 20.0;  // connector width between the lugs [match band]
band_gap   = band_w + 0.6;            // print clearance so the band slips in
bar_d      = 1.9;                     // quick-release / spring-bar hole dia
bar_z      = 6.0;                     // bar height above the back face
lug_ear    = 3.0;                     // lug thickness (X) outside the band gap
lug_reach  = 5.0;                     // how far the lugs extend past the body (Y)
lug_tall   = 10.5;                    // lug height (Z)
seat_r     = 26;                      // concave seat radius so the band wraps in

// ---- Flex ribbon entry (palm side, -Y) ------------------------------------
ribbon_w = 11; ribbon_h = 3.0;

// ---- Screw bosses ---------------------------------------------------------
screw_pilot = 1.5;         // M2 self-tap pilot
screw_head  = 3.8;         // countersink dia in lid
boss_d      = 5.0;
boss_inset  = 6;           // corner boss offset from the corners

// ===========================================================================
// Helpers
// ===========================================================================
module rrect(w, d, r) {
    hull() for (sx = [-1, 1], sy = [-1, 1])
        translate([sx * (w/2 - r), sy * (d/2 - r)]) circle(r);
}

// Solid outer body — the reference's "pillow": a squircle prism rounded on
// every edge by a sphere (Minkowski). Footprint stays W x L, height case_h,
// vertical corner radius stays corner_r; only the edges get the edge_r fillet.
// Flat vertical side walls keep the shell a uniform thickness and let the crown
// pass through cleanly. A small sphere $fn keeps the Minkowski fast.
module body_solid() {
    minkowski() {
        translate([0,0,edge_r])
            linear_extrude(case_h - 2*edge_r)
                rrect(W - 2*edge_r, L - 2*edge_r, max(corner_r - edge_r, 0.5));
        sphere(r = edge_r, $fn = 28);
    }
}

// Inner cavity (open top). Leaves floor_th at the bottom.
module cavity() {
    translate([0,0,floor_th])
        linear_extrude(case_h) rrect(W-2*wall, L-2*wall, max(corner_r-wall,1));
}

lip_h  = 3;          // alignment lip height on the lid
lip_t  = 1.4;        // lip wall thickness
cav_w  = W-2*wall;   // inner cavity width
cav_l  = L-2*wall;   // inner cavity length

// Corner boss centres
boss_x = W/2 - boss_inset;
boss_y = L/2 - boss_inset;
module corner_centres() {
    for (sx=[-1,1], sy=[-1,1]) translate([sx*boss_x, sy*boss_y, 0]) children();
}
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

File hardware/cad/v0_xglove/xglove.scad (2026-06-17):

$fn = 96;

// ==================================================
// ESP32-C3 Super Mini Wrist Enclosure
// Refined OpenSCAD source for print-ready case + lid
// ==================================================

// ---------- Board ----------
board_L = 22.52;
board_W = 18.00;
board_clearance = 1.10;

// ---------- Case ----------
wall = 2.80;
end_wall = 6.40;
floor_h = 2.10;
case_h = 10.80;
lid_h = 3.10;

strap_edge = 5.30;

bay_L = board_L + board_clearance*2;
bay_W = board_W + board_clearance*2;

L = bay_L + end_wall*2;
W = bay_W + wall*2 + strap_edge*2;
H = case_h;

// ---------- Surfacing ----------
corner_r = 4.30;
bay_r = 1.80;
body_bottom_chamfer = 0.70;
body_top_chamfer = 1.05;
body_face_inset = 0.72;
lid_bottom_chamfer = 0.42;
lid_top_chamfer = 0.72;
lid_face_inset = 0.55;
skin = 0.045;

// ---------- USB-C ----------
usb_w = 13.20;
usb_h = 5.80;
usb_z = floor_h + 0.85;
usb_r = 1.35;
usb_mouth_extra = 1.35;

// ---------- Apple Watch strap sockets ----------
strap_w = 22.40;
strap_h = 4.60;
strap_z = floor_h + 0.80;
strap_r = 1.20;
strap_socket_depth = end_wall - 0.60;
strap_mouth_extra = 1.35;

// ---------- Lid screws ----------
lid_screw_d = 2.25;
pilot_d = 1.70;
screw_head_d = 4.35;
screw_head_h = 1.28;
screw_inset = 5.35;
pilot_h = 4.60;
boss_d = 5.30;

// ---------- Lid lip ----------
lip_h = 1.55;
lip_clearance = 0.35;
lip_chamfer = 0.24;

// ---------- Board tray ----------
tray_h = 0.68;
rail_w = 1.05;
rail_h = 1.25;
clip_h = 0.56;
clip_w = 4.80;
tray_embed = 0.18;
rail_overlap = 0.18;
clip_overlap = 0.12;

// ---------- Layout ----------
gap = 9.00;
print_layout = true;
part = "all"; // "all", "case", "lid", "assembly"
show_tray = true;
show_bosses = true;

// ==================================================

module rounded_rect_2d(size=[10,10], r=2) {
    rr = max(0.01, min(r, min(size[0], size[1])/2 - 0.01));

    hull() {
        for (x=[rr, size[0]-rr])
        for (y=[rr, size[1]-rr])
            translate([x,y])
                circle(r=rr);
    }
}

module centered_profile(parent=[10,10], face=[8,8], r=1, z=0, h=skin) {
    translate([
        (parent[0]-face[0])/2,
        (parent[1]-face[1])/2,
        z
    ])
        linear_extrude(h)
            rounded_rect_2d(face, r);
}

module rounded_prism(size=[10,10,10], r=2) {
    linear_extrude(size[2])
        rounded_rect_2d([size[0], size[1]], r);
}

module chamfered_rounded_box(size=[10,10,10], r=2, bottom=0.6, top=0.8, inset=0.5) {
    face = [
        max(0.1, size[0] - inset*2),
        max(0.1, size[1] - inset*2)
    ];
    face_r = max(0.1, r - inset);
    mid_h = max(0.01, size[2] - bottom - top);

    union() {
        hull() {
            centered_profile([size[0], size[1]], face, face_r, 0, skin);
            centered_profile([size[0], size[1]], [size[0], size[1]], r, bottom, skin);
        }

        translate([0,0,bottom])
            rounded_prism([size[0], size[1], mid_h], r);

        hull() {
            centered_profile([size[0], size[1]], [size[0], size[1]], r, size[2]-top-skin, skin);
            centered_profile([size[0], size[1]], face, face_r, size[2]-skin, skin);
        }
    }
}

module rounded_slot_x(length=5, y_size=10, z_size=4, r=1) {
    rr = max(0.01, min(r, min(y_size, z_size)/2 - 0.01));

    hull() {
        for (y=[rr, y_size-rr])
        for (z=[rr, z_size-rr])
            translate([0,y,z])
                rotate([0,90,0])
                    cylinder(h=length, r=rr);
    }
}

module rounded_slot_y(length=5, x_size=10, z_size=4, r=1) {
    rr = max(0.01, min(r, min(x_size, z_size)/2 - 0.01));

    hull() {
        for (x=[rr, x_size-rr])
        for (z=[rr, z_size-rr])
            translate([x,0,z])
                rotate([-90,0,0])
                    cylinder(h=length, r=rr);
    }
}

module screw_positions(z=0) {
    for (x=[screw_inset, L-screw_inset])
    for (y=[screw_inset, W-screw_inset])
        translate([x,y,z])
            children();
}

module bay_origin() {
    translate([end_wall, wall + strap_edge, floor_h])
        children();
}

module board_origin() {
    translate([
        end_wall + board_clearance,
        wall + strap_edge + board_clearance,
        floor_h - tray_embed
    ])
        children();
}

module electronics_bay_cutout() {
    bay_origin()
        linear_extrude(H + 1)
            rounded_rect_2d([bay_L, bay_W], bay_r);
}

module usb_cutouts() {
    depth = wall + strap_edge + 1.20;

    translate([L/2 - usb_w/2, -0.60, usb_z])
        rounded_slot_y(depth + 0.60, usb_w, usb_h, usb_r);

    translate([
        L/2 - (usb_w + usb_mouth_extra*2)/2,
        -0.65,
        usb_z - usb_mouth_extra/2
    ])
        rounded_slot_y(
            1.25,
            usb_w + usb_mouth_extra*2,
            usb_h + usb_mouth_extra,
            usb_r + 0.32
        );
}

module strap_socket_cutouts() {
    y0 = W/2 - strap_w/2;
    z0 = strap_z;
    cut_len = strap_socket_depth + 0.60;

    translate([-0.60, y0, z0])
        rounded_slot_x(cut_len, strap_w, strap_h, strap_r);

    translate([L - strap_socket_depth, y0, z0])
        rounded_slot_x(cut_len, strap_w, strap_h, strap_r);

    translate([
        -0.65,
        W/2 - (strap_w + strap_mouth_extra*2)/2,
        z0 - strap_mouth_extra/2
    ])
        rounded_slot_x(
            1.35,
            strap_w + strap_mouth_extra*2,
            strap_h + strap_mouth_extra,
            strap_r + 0.34
        );

    translate([
        L - 0.70,
        W/2 - (strap_w + strap_mouth_extra*2)/2,
        z0 - strap_mouth_extra/2
    ])
        rounded_slot_x(
            1.35,
            strap_w + strap_mouth_extra*2,
            strap_h + strap_mouth_extra,
            strap_r + 0.34
        );
}

module bottom_screw_bosses() {
    screw_positions(floor_h)
        cylinder(h=H-floor_h-0.30, d=boss_d);
}

module bottom_screw_pilots() {
    screw_positions(H - pilot_h)
        cylinder(h=pilot_h + 0.45, d=pilot_d);
}

module board_tray() {
    board_origin()
        cube([board_L, board_W, tray_h], false);

    board_origin()
        translate([0, -rail_w, 0])
            cube([board_L, rail_w + rail_overlap, rail_h], false);

    board_origin()
        translate([0, board_W - rail_overlap, 0])
            cube([board_L, rail_w + rail_overlap, rail_h], false);

    board_origin()
        translate([-rail_w, 0, 0])
            cube([rail_w + rail_overlap, board_W, rail_h], false);

    board_origin()
        translate([board_L - rail_overlap, 0, 0])
            cube([rail_w + rail_overlap, board_W, rail_h], false);

    board_origin()
        translate([3.00, -rail_w, rail_h - clip_overlap])
            cube([clip_w, rail_w + 0.75, clip_h + clip_overlap], false);

    board_origin()
        translate([board_L - 3.00 - clip_w, -rail_w, rail_h - clip_overlap])
            cube([clip_w, rail_w + 0.75, clip_h + clip_overlap], false);

    board_origin()
        translate([3.00, board_W - 0.20, rail_h - clip_overlap])
            cube([clip_w, rail_w + 0.75, clip_h + clip_overlap], false);

    board_origin()
        translate([board_L - 3.00 - clip_w, board_W - 0.20, rail_h - clip_overlap])
            cube([clip_w, rail_w + 0.75, clip_h + clip_overlap], false);
}

module bottom_case() {
    color([1.0, 0.76, 0.02])
    union() {
        difference() {
            union() {
                chamfered_rounded_box(
                    [L,W,H],
                    corner_r,
                    body_bottom_chamfer,
                    body_top_chamfer,
                    body_face_inset
                );
                if (show_bosses)
                    bottom_screw_bosses();
            }

            electronics_bay_cutout();
            usb_cutouts();
            strap_socket_cutouts();
            bottom_screw_pilots();
        }

        if (show_tray)
            board_tray();
    }
}

module lid_lip() {
    translate([
        end_wall + lip_clearance,
        wall + strap_edge + lip_clearance,
        -lip_h
    ])
        chamfered_rounded_box(
            [
                bay_L - lip_clearance*2,
                bay_W - lip_clearance*2,
                lip_h + skin
            ],
            max(0.35, bay_r - lip_clearance),
            lip_chamfer,
            lip_chamfer,
            0.18
        );
}

module lid_screw_cutouts() {
    screw_positions(-lip_h - 0.20)
        cylinder(h=lid_h + lip_h + 0.55, d=lid_screw_d);

    screw_positions(lid_h - screw_head_h)
        cylinder(h=screw_head_h + 0.35, d=screw_head_d);

    screw_positions(lid_h - 0.22)
        cylinder(h=0.32, d=screw_head_d + 0.45);
}

module lid_top_recess() {
    panel_inset = 3.15;

    translate([panel_inset, panel_inset, lid_h - 0.22])
        linear_extrude(0.30)
            rounded_rect_2d(
                [L - panel_inset*2, W - panel_inset*2],
                corner_r - 1.10
            );
}
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

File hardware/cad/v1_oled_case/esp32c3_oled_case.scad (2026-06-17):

$fn = 96;

// ESP32-C3 + OLED enclosure
// Units: millimeters

// ---------- Printable output ----------
part = "all";          // "all", "case", "lid", "mount", "assembly"
print_layout = true;   // true: lay lid upside-down for printing

// ---------- Hardware ----------
board_L = 24.0;        // ESP32-C3 board length, 2.4 cm
board_W = 18.0;        // ESP32-C3 board width, 1.8 cm
board_clearance = 0.7;

oled_L = 34.0;         // OLED module length, 3.4 cm
oled_W = 21.0;         // OLED module width, 2.1 cm
oled_clearance = 0.7;
oled_header_on_right = true;

// ---------- Case ----------
L = 52.0;
W = 38.0;
case_H = 14.0;
lid_H = 3.2;
wall = 2.2;
floor_H = 2.0;
gap = 8.0;

corner_r = 4.0;
inner_r = 2.6;
body_bottom_chamfer = 0.55;
body_top_chamfer = 0.75;
body_face_inset = 0.55;
lid_bottom_chamfer = 0.35;
lid_top_chamfer = 0.55;
lid_face_inset = 0.42;
skin = 0.04;

// ---------- USB-C opening ----------
// Opening is on the long side of the case, centered on the ESP32-C3 port.
usb_slot_w = 15.0;     // requested 1.5 cm
usb_slot_h = 6.0;
usb_slot_z = floor_H + 0.75;
usb_slot_r = 1.35;
usb_mouth_extra = 1.2;

// ---------- External wire exit ----------
wire_exit_w = 7.0;
wire_exit_h = 4.8;
wire_exit_z = floor_H + 4.0;
wire_exit_r = 1.8;

// ---------- OLED top pocket and pass-through ----------
oled_pocket_depth = 1.35;
oled_pocket_r = 1.6;
oled_wire_slot_L = 12.0;
oled_wire_slot_W = 5.5;
oled_wire_slot_edge_gap = 1.8;
oled_wire_slot_r = 1.1;

// ---------- Lid screws ----------
screw_inset = 5.7;
boss_d = 5.4;
pilot_d = 1.65;        // M2 self-tapping pilot
lid_screw_d = 2.35;
screw_head_d = 4.8;
screw_head_H = 1.25;
boss_top_gap = 0.45;
boss_embed = 0.18;

// ---------- Lid alignment tabs ----------
lip_H = 1.65;
lip_clearance = 0.30;
lip_tab_T = 1.15;
lip_tab_L = 13.0;

// ---------- Board tray ----------
tray_H = 0.75;
tray_embed = 0.16;
rail_W = 1.0;
rail_H = 1.35;
rail_overlap = 0.15;
front_usb_gap = 17.0;
clip_L = 4.6;
clip_H = 0.55;
clip_overlap = 0.12;

// ---------- Glove mount ----------
mount_L = 64.0;
mount_W = 50.0;
mount_H = 2.8;
mount_r = 5.2;
mount_bottom_chamfer = 0.45;
mount_top_chamfer = 0.55;
mount_face_inset = 0.50;
mount_x = (L - mount_L) / 2;
mount_y = (W - mount_W) / 2;

velcro_w = 22.0;
velcro_clearance = 2.4;
velcro_slot_L = velcro_w + velcro_clearance;
velcro_slot_W = 5.2;
velcro_slot_r = 1.45;
velcro_slot_edge = 8.5;
velcro_channel_depth = 1.05;
velcro_channel_clearance = 1.8;

glove_sew_slot_L = 11.5;
glove_sew_slot_W = 3.4;
glove_sew_slot_r = 1.25;
glove_sew_slot_x = 4.3;
glove_sew_slot_y_offset = 10.0;

mount_fastener_x_offset = 13.0;
mount_fastener_y = W - wall - 5.4;
mount_fastener_boss_d = 6.2;
mount_fastener_boss_H = 3.7;
mount_fastener_pilot_d = 1.65;
mount_fastener_clearance_d = 2.35;
mount_fastener_head_d = 4.9;
mount_fastener_head_H = 1.2;

board_x = (L - board_L) / 2;
board_y = wall + board_clearance;
oled_x = (L - oled_L) / 2;
oled_y = (W - oled_W) / 2;
oled_pocket_x = oled_x - oled_clearance;
oled_pocket_y = oled_y - oled_clearance;
oled_pocket_L = oled_L + oled_clearance * 2;
oled_pocket_W = oled_W + oled_clearance * 2;
oled_wire_slot_x = oled_header_on_right
    ? oled_x + oled_L - oled_wire_slot_L - oled_wire_slot_edge_gap
    : oled_x + oled_wire_slot_edge_gap;
oled_wire_slot_y = (W - oled_wire_slot_W) / 2;
mount_fastener_xs = [L / 2 - mount_fastener_x_offset, L / 2 + mount_fastener_x_offset];

module rounded_rect_2d(size=[10,10], r=2) {
    rr = max(0.01, min(r, min(size[0], size[1]) / 2 - 0.01));

    hull() {
        for (x=[rr, size[0] - rr])
        for (y=[rr, size[1] - rr])
            translate([x, y])
                circle(r=rr);
    }
}

module centered_profile(parent=[10,10], face=[8,8], r=1, z=0, h=skin) {
    translate([(parent[0] - face[0]) / 2, (parent[1] - face[1]) / 2, z])
        linear_extrude(h)
            rounded_rect_2d(face, r);
}

module rounded_prism(size=[10,10,10], r=2) {
    linear_extrude(size[2])
        rounded_rect_2d([size[0], size[1]], r);
}

module chamfered_rounded_box(size=[10,10,10], r=2, bottom=0.5, top=0.5, inset=0.4) {
    face = [
        max(0.1, size[0] - inset * 2),
        max(0.1, size[1] - inset * 2)
    ];
    face_r = max(0.1, r - inset);
    mid_H = max(0.01, size[2] - bottom - top);

    union() {
        hull() {
            centered_profile([size[0], size[1]], face, face_r, 0, skin);
            centered_profile([size[0], size[1]], [size[0], size[1]], r, bottom, skin);
        }

        translate([0, 0, bottom])
            rounded_prism([size[0], size[1], mid_H], r);

        hull() {
            centered_profile([size[0], size[1]], [size[0], size[1]], r, size[2] - top - skin, skin);
            centered_profile([size[0], size[1]], face, face_r, size[2] - skin, skin);
        }
    }
}

module rounded_slot_x(length=5, y_size=10, z_size=4, r=1) {
    rr = max(0.01, min(r, min(y_size, z_size) / 2 - 0.01));

    hull() {
        for (y=[rr, y_size - rr])
        for (z=[rr, z_size - rr])
            translate([0, y, z])
                rotate([0, 90, 0])
                    cylinder(h=length, r=rr);
    }
}

module rounded_slot_y(length=5, x_size=10, z_size=4, r=1) {
    rr = max(0.01, min(r, min(x_size, z_size) / 2 - 0.01));
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

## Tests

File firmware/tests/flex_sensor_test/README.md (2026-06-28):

# Flex Sensor Gesture Test (5 channels)

Reads the glove's five flex sensors on GPIO0..4 (ESP32-C3 ADC1 — the same pins
`esp32_glove_ble` uses), decides per finger whether it is bent, and turns the five
bend states into a 5-bit pattern. Each pattern maps to one Thai phrase from the
gesture chart: hold a finger combo and the firmware prints `SAY:<phrase>` so the
host bridge (`greet_bridge.py`) speaks it. It also prints per-finger
delta-from-baseline to the serial monitor and draws live bar graphs on the SH1106
OLED.

## Wiring

Each finger is a resistive divider (one fixed resistor per channel):

```
3V3 --- [flex sensor] ---+--- ADC pin (GPIO0..4)
                         |
                       [R_fixed ~22k-47k] --- GND
```

Bending the sensor raises its resistance, pulling the ADC node down. Pick a
fixed resistor near the sensor's flat resistance for the widest swing.

| Finger | ADC pin | |
|---|---|---|
| F1 thumb  | GPIO0 | ADC1_0 |
| F2 index  | GPIO1 | ADC1_1 |
| F3 middle | GPIO2 | ADC1_2 ⚠️ strapping |
| F4 ring | GPIO3 | ADC1_3 |
| F5 pinky  | GPIO4 | ADC1_4 |
| OLED SDA  | GPIO5 | I2C 0x3C |
| OLED SCL  | GPIO6 | |

> **GPIO2 is a C3 strapping pin.** Keep its divider node HIGH at rest (sensor on
> the high side, as drawn) so a bent finger at power-on can't force the board into
> download mode.

## Build & upload (ESP32-C3 SuperMini)

```bash
arduino-cli compile --fqbn esp32:esp32:esp32c3 firmware/tests/flex_sensor_test
arduino-cli upload -p /dev/ttyACM0 --fqbn esp32:esp32:esp32c3 firmware/tests/flex_sensor_test
arduino-cli monitor -p /dev/ttyACM0 -c baudrate=115200
```

Or use the repo helper: `./up.sh --list` then pick this sketch.

## Usage

On boot it captures a flat-hand baseline (hold the hand straight), then watches
for gestures:

- **Flat hand** → all deltas sit near `0`, no finger bent.
- **Bend a finger past the ON threshold** → it counts as bent (shown as `*` on
  the OLED); its bar also grows by `delta`.
- **Hold a finger combo steady** (~300 ms) → if it matches a gesture the firmware
  prints `SAY:<thai phrase>` on serial and the OLED header shows the English
  label. It fires once; relax to flat (or form a different combo) to fire again.
- **Release** → fingers return to ~`0` and the gesture re-arms.
- A momentary disconnect (raw dropping toward 0) is rejected as a glitch: the
  value is held and marked `X`, and the finger keeps its last bend state.
- Press **BOOT** (GPIO9) with the hand flat any time to re-capture the baseline.

## Gestures

The 10 most-useful phrases, each on an easy 1–2 finger (or full-fist) combo.
Finger codes: **1**=thumb (โป้ง), **2**=index (ชี้), **3**=middle (กลาง),
**4**=ring (นาง), **5**=pinky (ก้อย). Bend (งอ) the listed fingers and hold.
Type `g` in the serial monitor for this list at runtime.

| Fingers | Phrase | English | |
|---|---|---|---|
| 1 2 3 4 5 | ช่วยด้วย | help | (กำมือ / fist) |
| 1 2 | เจ็บ | hurt | |
| 2 | ใช่ | yes | |
| 2 3 | ไม่ใช่ | no | |
| 1 | หิวข้าว | hungry | |
| 5 | ต้องการน้ำ | need water | |
| 4 5 | เข้าห้องน้ำ | bathroom | |
| 1 5 | สวัสดี | hello | |
| 2 3 4 5 | ขอบคุณ | thank you | (สี่นิ้ว ไม่รวมโป้ง) |
| 2 3 4 | ไม่สบาย | sick | |

## Serial calibration

Type a command + Enter in the serial monitor (115200 baud) to calibrate live —
no re-flash needed. Settings persist until reset.

| Command | Action |
|---|---|
| `c` / `cal` | re-capture the flat-hand baseline (same as BOOT) |
| `a <0.01..1.0>` | set EMA alpha — **lower = steadier**, higher = snappier |
| `s <1..64>` | samples averaged per read — **more = steadier**, slower |
| `m <0\|1>` | median filter off/on — `1` gives the best spike rejection |
| `n <50..1400>` | bend-**ON** delta — a finger counts as bent above this |
| `f <30..1400>` | bend-**OFF** delta — a finger counts as straight below this |
| `g` / `gestures` | print the full gesture table |
| `?` / `show` | print current settings |
| `h` / `help` | list commands |

**For the steadiest values:** keep `m 1` (median, default on), raise samples
(`s 24`), and lower alpha (`a 0.15`). If readings feel laggy, nudge alpha back up.

**Tuning bend detection:** watch the per-finger `delta` while bending. Set `n`
(bend-ON) comfortably below a full bend and `f` (bend-OFF) above the resting
noise; the gap between them is hysteresis that stops a finger from chattering.
Defaults are `n 200` / `f 120`.

Static tunables near the top of the sketch: defaults for `emaAlpha`,
`samplesPerRead`, `medianFilter`, `bendOnDelta`, `bendOffDelta`, plus
`GLITCH_FLOOR` (disconnect threshold) and `BEND_FULL_SCALE` (bar sensitivity).

## OLED

Needs the `U8g2` library (`arduino-cli lib install U8g2`). The OLED is on by
default (SDA=GPIO5, SCL=GPIO6, address 0x3C). If the display isn't found the
sketch keeps running on serial only. If your panel is a true SSD1306, swap the
`U8G2_SH1106_...` constructor for `U8G2_SSD1306_...`.

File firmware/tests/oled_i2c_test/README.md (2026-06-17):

# ESP32 OLED Network Status

Default wiring for a common ESP32 DevKit:

- OLED VCC -> 3V3
- OLED GND -> GND
- OLED SDA -> GPIO 21
- OLED SCL -> GPIO 22

Install libraries:

```bash
arduino-cli lib install U8g2
```

Compile for a generic ESP32 Dev Module from the repo root:

```bash
arduino-cli compile --fqbn esp32:esp32:esp32 firmware/tests/oled_i2c_test
```

Upload:

```bash
arduino-cli upload -p /dev/ttyACM0 --fqbn esp32:esp32:esp32 firmware/tests/oled_i2c_test
```

Open serial monitor:

```bash
arduino-cli monitor -p /dev/ttyACM0 -c baudrate=115200
```

If the OLED is 128x32, change `SCREEN_HEIGHT` in `oled_i2c_test.ino` from `64` to `32`.
If your board uses different I2C pins, change `I2C_SDA` and `I2C_SCL`.

Set WiFi credentials near the top of `oled_i2c_test.ino`:

```cpp
#define WIFI_SSID "your-wifi-name"
#define WIFI_PASSWORD "your-wifi-password"
```

If `WIFI_SSID` is empty, the screen shows WiFi scan status instead of connecting.

This sketch currently uses the `SH1106 128x64` U8g2 driver because many 1.3" blue I2C OLED modules use SH1106 even when sold as "SSD1306".

If your display is definitely SSD1306, replace this line:

```cpp
U8G2_SH1106_128X64_NONAME_F_HW_I2C display(U8G2_R0, U8X8_PIN_NONE);
```

with:

```cpp
U8G2_SSD1306_128X64_NONAME_F_HW_I2C display(U8G2_R0, U8X8_PIN_NONE);
```

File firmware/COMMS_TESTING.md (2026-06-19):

# ESP32-C3 ↔ ESP32-C3 communication — every method

Three fallback sketches to get two ESP32-C3 SuperMini boards talking, and to
pinpoint *why* if they don't. Flash the **same** sketch to **both** boards.

On-board LED (GPIO8, active-low) blinks on every packet **received** — so you
can confirm RX without a laptop.

| Sketch | Radio path | Use it to… |
| --- | --- | --- |
| `esp32_espnow_diag` | ESP-NOW broadcast, fixed ch 1 | Normal test + isolate a dead board (TX/RX role switch) |
| `esp32_espnow_scan` | ESP-NOW, hops ch 1–13 | Find the peer's channel; prove RX hardware works |
| `esp32_wifi_link` | Plain Wi-Fi UDP (SoftAP+STA) | Total fallback when ESP-NOW won't cooperate |

## Decision flow

```
1. Flash esp32_espnow_diag to BOTH boards, power BOTH, open both monitors.
   - Both show "<<< RECV" + LED blinks  -> DONE. Link works.
   - One side never shows RECV          -> go to step 2.

2. Flash esp32_espnow_diag (ROLE_TX) to the "good" board,
   esp32_espnow_scan to the suspect.
   - Scanner prints "HEARD peer on channel N"
        -> channel mismatch was the issue; RX hardware is fine.
   - Scanner shows "NONE" every sweep, other board powered
        -> suspect board's RX is dead. Swap the board.

3. Still nothing? Flash esp32_wifi_link to both.
   - Works  -> radios are fine; the ESP-NOW issue is config; revisit step 1.
   - Fails too -> wiring/power/antenna or a genuinely bad board.
```

## Commands

```bash
# Flash one board (repeat after plugging in the other):
./up.sh --sketch firmware/esp32_espnow_diag
./up.sh --sketch firmware/esp32_espnow_scan
./up.sh --sketch firmware/esp32_wifi_link

# Watch a board (find the port with: arduino-cli board list):
./up.sh --monitor-only --port /dev/ttyACM0
./up.sh --monitor-only --port /dev/ttyACM1
```

## Notes / gotchas

- **`send -> OK` proves nothing** in broadcast mode — no ACK. Only `<<< RECV`
  (or the LED blink) confirms the link.
- **Both boards must be powered at the same time** for any test.
- **Role switch** in `esp32_espnow_diag`: edit `#define ROLE ...` to
  `ROLE_TX` / `ROLE_RX` to test one direction at a time.
- **MACs**: `esp32_wifi_link` picks AP/STA by MAC (BOARD_A→AP, BOARD_B→STA).
  Re-read MACs with `firmware/esp32_espnow_mac` if the defaults aren't yours.
- Cheap ESP32-C3 boards that **transmit fine but never receive** are a known,
  common hardware fault — step 2 is the definitive check for it.
```

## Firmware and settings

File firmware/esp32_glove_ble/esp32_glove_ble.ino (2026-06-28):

// ============================================================================
// ESP32 BLE Glove Firmware
// 5x flex sensors + MPU6050 (accel/gyro) + battery monitor + SH1106 OLED,
// exposed over a single BLE characteristic for the Android app in this repo.
// ============================================================================

#include <Arduino.h>
#include <BLE2902.h>
#include <BLEDevice.h>
#include <BLEServer.h>
#include <BLEUtils.h>
#include <Preferences.h>

#define FW_VERSION "2.3.0"

#ifndef GLOVE_ENABLE_OLED
#define GLOVE_ENABLE_OLED 1
#endif

#ifndef GLOVE_ENABLE_IMU
#define GLOVE_ENABLE_IMU 1
#endif

// The OLED and the MPU6050 share the same I2C bus, so Wire is needed whenever
// either one is enabled.
#if GLOVE_ENABLE_OLED || GLOVE_ENABLE_IMU
#include <Wire.h>
// ESP32-C3 SuperMini: GPIO5/6 are free (avoid 8/9 = LED/BOOT, 20/21 = serial).
static const int I2C_SDA_PIN = 5;
static const int I2C_SCL_PIN = 6;
static const uint32_t I2C_CLOCK_HZ = 400000;
#endif

#if GLOVE_ENABLE_OLED
#include <U8g2lib.h>
#endif

// ---------------------------------------------------------------------------
// Configuration
// ---------------------------------------------------------------------------

// Android app contract.
static const char* SERVICE_UUID = "0000ffe0-0000-1000-8000-00805f9b34fb";
static const char* CHARACTERISTIC_UUID = "0000ffe1-0000-1000-8000-00805f9b34fb";

// Change these to match your glove wiring.
// ESP32-C3 SuperMini: only GPIO0..4 expose ADC1, so the 5 flex sensors use them
// all. WARNING: GPIO2 is a boot strapping pin on the C3 and must NOT be held LOW
// at power-on, or the chip can drop into download mode / fail to boot. Wire the
// flex divider on this channel so the pin floats HIGH at rest (e.g. put the flex
// resistor on the high side), or accept that a fully-bent finger at boot may
// hang the device. Truly removing the risk means dropping to 4 channels or
// moving the I2C bus to free a non-strapping ADC pin -- both are wiring choices.
static const int FLEX_PINS[] = {0, 1, 2, 3, 4};
static const int FLEX_COUNT = sizeof(FLEX_PINS) / sizeof(FLEX_PINS[0]);
static const int BATTERY_PIN = -1; // No ADC channel left on C3 (0..4 used by flex). Set to a pin to re-enable.
static const float BATTERY_DIVIDER_RATIO = 2.0f; // 100k/100k divider = 2.0.

static const char* DEFAULT_DEVICE_NAME = "Glove-ESP32";
static const size_t MAX_DEVICE_NAME_CHARS = 20;

// Telemetry rate is runtime-adjustable via the RATE:<ms> command.
static const uint16_t TELEMETRY_DEFAULT_INTERVAL_MS = 100;
static const uint16_t TELEMETRY_MIN_INTERVAL_MS = 20;
static const uint16_t TELEMETRY_MAX_INTERVAL_MS = 1000;

// Exponential moving average weight for flex readings (0..1, higher = snappier).
static const float FLEX_EMA_ALPHA = 0.45f;
static const uint32_t BATTERY_READ_INTERVAL_MS = 2000;

// Adaptive baseline: slowly corrects flat-hand drift caused by flex sensor
// mechanical hysteresis after repeated bending.
static const float ADAPTIVE_BASELINE_ALPHA = 0.005f;  // ~20s time constant at 40ms sample rate
static const int ADAPTIVE_IDLE_THRESHOLD = 150;        // below GESTURE_BEND_ON=200; finger is "at rest"
static const uint32_t ADAPTIVE_IDLE_DURATION_MS = 2000;
static const uint32_t ADAPTIVE_NVS_SAVE_INTERVAL_MS = 30000;

#if GLOVE_ENABLE_IMU
// MPU6050 on the shared I2C bus (same SDA/SCL as the OLED). AD0 low = 0x68.
static const uint8_t MPU_ADDR_LOW = 0x68;
static const uint8_t MPU_ADDR_HIGH = 0x69;
static const uint8_t MPU_REG_PWR_MGMT_1 = 0x6B;
static const uint8_t MPU_REG_WHO_AM_I = 0x75;
static const uint8_t MPU_REG_ACCEL_XOUT_H = 0x3B;
#endif

#if GLOVE_ENABLE_OLED
static const uint8_t OLED_RESET_PIN = U8X8_PIN_NONE;
static const uint8_t OLED_I2C_ADDRESS = 0x3C;
static const uint32_t OLED_REFRESH_IDLE_MS = 500;
static const uint32_t OLED_REFRESH_STREAMING_MS = 100;
static const uint8_t OLED_BOOT_FRAMES = 34;
static const uint8_t OLED_BOOT_FRAME_DELAY_MS = 28;
static const int OLED_FLEX_DELTA_FULL_SCALE = 1400;
static const int OLED_BATTERY_MIN_MV = 3300;
static const int OLED_BATTERY_MAX_MV = 4200;
static const uint8_t OLED_LOW_BATTERY_PERCENT = 15;
static const uint32_t SCREENSAVER_TIMEOUT_MS = 25000;
static const uint8_t OLED_DEFAULT_BRIGHTNESS = 70; // 0..100, user-adjustable via BRIGHT:.
static const uint8_t CONNECT_ANIM_FRAMES = 18;
static const uint8_t WAVE_SAMPLES = 64;
static const uint8_t RAIN_COLS = 16;

enum OledPage : uint8_t {
    OLED_PAGE_DASHBOARD = 0,
    OLED_PAGE_TELEMETRY = 1,
    OLED_PAGE_SYSTEM = 2,
    OLED_PAGE_HAND = 3,
    OLED_PAGE_WAVE = 4,
    OLED_PAGE_COUNT = 5
};
#endif

// ---------------------------------------------------------------------------
// Gesture recognition
// ---------------------------------------------------------------------------
// Each finger contributes one bit to a 5-bit pattern (1 = bent). Bit order
// matches FLEX_PINS: bit0 = F1 thumb .. bit4 = F5 pinky. A bent finger combo,
// held briefly, maps to one Thai phrase from the glove's gesture chart -- it is
// emitted as "GEST:<phrase>" over BLE (for the Android app to speak) and as
// "SAY:<phrase>" over serial (for the host greet_bridge.py to speak). This
// mirrors firmware/tests/flex_sensor_test so the same chart works in both.
#define B_THUMB  0x01  // F1 (โป้ง)
#define B_INDEX  0x02  // F2 (ชี้)
#define B_MIDDLE 0x04  // F3 (กลาง)
#define B_RING   0x08  // F4 (นาง)
#define B_PINKY  0x10  // F5 (ก้อย)

// A finger flips to "bent" once |delta| rises past GESTURE_BEND_ON and back to
// "straight" once it falls below GESTURE_BEND_OFF; the gap is hysteresis so a
// finger hovering at the edge can't chatter between bent/straight.
static const int GESTURE_BEND_ON = 200;
static const int GESTURE_BEND_OFF = 120;
// A non-zero pattern must hold unchanged this long before it fires, so the
// transient patterns you sweep through while curling fingers are ignored.
static const uint32_t GESTURE_SETTLE_MS = 300;
// Flex sampling cadence for gesture detection, independent of telemetry so it
// works whether or not a BLE client is connected/streaming.
static const uint32_t GESTURE_SAMPLE_MS = 40;
// Readings below this look like a disconnect; the finger holds its last state.
static const int GESTURE_GLITCH_FLOOR = 100;
// Smoothing for the gesture sampler's own EMA (snappy enough to catch a hold).
static const float GESTURE_EMA_ALPHA = 0.35f;

struct Gesture {
    uint8_t mask;
    const char* thai;
    const char* en;
};

// The 10 most-useful phrases on easy 1-2 finger (or full-fist) combos. Every
// mask is unique. Keep in sync with firmware/tests/flex_sensor_test.
static const Gesture GESTURES[] = {
    { B_THUMB | B_INDEX | B_MIDDLE | B_RING | B_PINKY, "ช่วยด้วย", "help" },    // 1+2+3+4+5 (fist)
    { B_THUMB | B_INDEX,                      "เจ็บ",         "hurt" },          // 1+2
    { B_INDEX,                                "ใช่",          "yes" },           // 2
    { B_INDEX | B_MIDDLE,                     "ไม่ใช่",        "no" },            // 2+3
    { B_THUMB,                                "หิวข้าว",      "hungry" },        // 1
    { B_PINKY,                                "ต้องการน้ำ",   "need water" },     // 5
    { B_RING | B_PINKY,                       "เข้าห้องน้ำ",   "bathroom" },      // 4+5
    { B_THUMB | B_PINKY,                      "สวัสดี",       "hello" },         // 1+5
    { B_INDEX | B_MIDDLE | B_RING | B_PINKY,  "ขอบคุณ",      "thank you" },     // 2+3+4+5
    { B_INDEX | B_MIDDLE | B_RING,            "ไม่สบาย",      "sick" },          // 2+3+4
};
static const int GESTURE_COUNT = sizeof(GESTURES) / sizeof(GESTURES[0]);

// ---------------------------------------------------------------------------
// State
// ---------------------------------------------------------------------------

Preferences prefs;
BLEServer* bleServer = nullptr;
BLECharacteristic* gloveCharacteristic = nullptr;

String deviceName;
// Which hand this glove is, for the dual-hand Android app. 0 = unset, 'L', 'R'.
// The app assigns the left/right slot from the advertised BLE name, so when this
// is set the side is appended to the advertised name (e.g. "Glove-ESP32-L").
char gloveHand = 0;
bool deviceConnected = false;
bool oldDeviceConnected = false;
bool streaming = true;
uint16_t telemetryIntervalMs = TELEMETRY_DEFAULT_INTERVAL_MS;
uint32_t lastTelemetryMs = 0;
uint32_t telemetryPacketCount = 0;
uint16_t flexBaseline[FLEX_COUNT] = {0};

// Commands arrive on the BLE stack's thread; they are queued here and run from
// loop() so slow work (OLED animations, NVS writes) never blocks the stack.
String pendingCommand;
volatile bool commandPending = false;

// Advertising restart is scheduled instead of blocking loop() with delay().
uint32_t advertisingRestartAtMs = 0;

float flexEma[FLEX_COUNT] = {0};
bool flexEmaReady = false;

// Gesture recognition uses its own flex sampler (separate EMA + baseline) so it
// runs continuously and never perturbs the app-facing telemetry pipeline above.
float gestureEma[FLEX_COUNT] = {0};
bool gestureEmaReady = false;
int gestureBaseline[FLEX_COUNT] = {0};

bool adaptiveIdleTracking = false;
uint32_t adaptiveIdleSince = 0;
uint32_t lastAdaptiveNvsSaveMs = 0;
bool fingerBent[FLEX_COUNT] = {false};
uint8_t gestureMaskCandidate = 0;   // pattern currently being held / settled
uint32_t gestureCandidateSince = 0; // millis() when that pattern began
uint8_t gestureSpokenMask = 0;      // last pattern spoken; re-arms at neutral
uint32_t lastGestureSampleMs = 0;

int cachedBatteryMv = -1;
uint32_t lastBatteryReadMs = 0;

struct TelemetrySnapshot {
    int flex[FLEX_COUNT] = {0};
    int batteryMv = -1;
#if GLOVE_ENABLE_IMU
    // Raw int16 counts straight from the MPU6050; the app scales them.
    int16_t accel[3] = {0, 0, 0};
    int16_t gyro[3] = {0, 0, 0};
    bool imuValid = false;
#endif
};

TelemetrySnapshot latestTelemetry;
bool latestTelemetryValid = false;

#if GLOVE_ENABLE_IMU
uint8_t mpuAddress = 0; // 0 = not detected
bool imuReady = false;
#endif

#if GLOVE_ENABLE_OLED
U8G2_SH1106_128X64_NONAME_F_HW_I2C oled(U8G2_R0, OLED_RESET_PIN, I2C_SCL_PIN, I2C_SDA_PIN);
bool oledReady = false;
uint8_t oledBrightness = OLED_DEFAULT_BRIGHTNESS; // 0..100
uint32_t lastOledRefreshMs = 0;
OledPage oledPage = OLED_PAGE_DASHBOARD;
uint32_t lastActivityMs = 0;
bool playConnectAnim = false;
uint8_t connectAnimFrame = 0;
static uint8_t waveBuffer[FLEX_COUNT][WAVE_SAMPLES];
static uint8_t waveHead = 0;
static int8_t rainDropY[RAIN_COLS];
static uint8_t rainDropLen[RAIN_COLS];
// Last recognised gesture, shown as a brief overlay (English: the OLED font has
// no Thai glyphs). Empty / past-deadline = nothing to draw.
char gestureLabel[20] = "";
uint32_t gestureLabelUntilMs = 0;
#endif

// ---------------------------------------------------------------------------
// BLE callbacks
// ---------------------------------------------------------------------------

class ServerCallbacks : public BLEServerCallbacks {
    void onConnect(BLEServer*) override {
        deviceConnected = true;
#if GLOVE_ENABLE_OLED
        lastActivityMs = millis();
        playConnectAnim = true;
        connectAnimFrame = 0;
#endif
    }

    void onDisconnect(BLEServer*) override {
        deviceConnected = false;
#if GLOVE_ENABLE_OLED
        lastActivityMs = millis();
#endif
    }
};

// ---------------------------------------------------------------------------
// Helpers
// ---------------------------------------------------------------------------

static String trimCommand(String value) {
    value.trim();
    value.replace("\r", "");
    value.replace("\n", "");
    return value;
}

static uint16_t readAnalogAverage(int pin, int samples = 8) {
    uint32_t total = 0;
    for (int i = 0; i < samples; i++) {
        total += analogRead(pin);
        delayMicroseconds(250);
    }
    return total / samples;
}

// Uses the factory ADC calibration instead of assuming a linear 3.3V scale.
static int readBatteryMillivoltsNow() {
    if (BATTERY_PIN < 0) return -1;
    uint32_t total = 0;
    for (int i = 0; i < 8; i++) {
        total += analogReadMilliVolts(BATTERY_PIN);
        delayMicroseconds(250);
    }
    return static_cast<int>((total / 8) * BATTERY_DIVIDER_RATIO);
}

static int batteryMillivolts() {
    if (BATTERY_PIN < 0) return -1;
    uint32_t now = millis();
    if (cachedBatteryMv < 0 || now - lastBatteryReadMs >= BATTERY_READ_INTERVAL_MS) {
        cachedBatteryMv = readBatteryMillivoltsNow();
        lastBatteryReadMs = now;
    }
    return cachedBatteryMv;
}

#if GLOVE_ENABLE_IMU
static void mpuWriteReg(uint8_t reg, uint8_t value) {
    Wire.beginTransmission(mpuAddress);
    Wire.write(reg);
    Wire.write(value);
    Wire.endTransmission();
}

static uint8_t mpuReadReg(uint8_t reg) {
    Wire.beginTransmission(mpuAddress);
    Wire.write(reg);
    Wire.endTransmission(false);
    Wire.requestFrom(mpuAddress, static_cast<uint8_t>(1));
    return Wire.available() ? Wire.read() : 0;
}

// Reads accel XYZ, temp (discarded), gyro XYZ as big-endian int16.
static bool mpuReadMotion(int16_t accel[3], int16_t gyro[3]) {
    Wire.beginTransmission(mpuAddress);
    Wire.write(MPU_REG_ACCEL_XOUT_H);
    if (Wire.endTransmission(false) != 0) return false;
    if (Wire.requestFrom(mpuAddress, static_cast<uint8_t>(14)) != 14) return false;

    // Read high/low into explicit temporaries: the order of two Wire.read()
    // calls inside one expression is unspecified and could swap the bytes.
    for (int i = 0; i < 3; i++) {
        uint8_t hi = Wire.read();
        uint8_t lo = Wire.read();
        accel[i] = static_cast<int16_t>((hi << 8) | lo);
    }
    Wire.read();
    Wire.read(); // skip temperature
    for (int i = 0; i < 3; i++) {
        uint8_t hi = Wire.read();
        uint8_t lo = Wire.read();
        gyro[i] = static_cast<int16_t>((hi << 8) | lo);
    }
    return true;
}
#endif

static TelemetrySnapshot readTelemetrySnapshot() {
    TelemetrySnapshot snapshot;
    for (int i = 0; i < FLEX_COUNT; i++) {
        int raw = readAnalogAverage(FLEX_PINS[i]);
        if (!flexEmaReady) {
            flexEma[i] = raw;
        } else {
            flexEma[i] += FLEX_EMA_ALPHA * (raw - flexEma[i]);
        }
        int filtered = static_cast<int>(lroundf(flexEma[i]));
        snapshot.flex[i] = flexBaseline[i] == 0
            ? filtered
            : filtered - static_cast<int>(flexBaseline[i]);
    }
    flexEmaReady = true;
    snapshot.batteryMv = batteryMillivolts();
#if GLOVE_ENABLE_IMU
    if (imuReady) {
        snapshot.imuValid = mpuReadMotion(snapshot.accel, snapshot.gyro);
    }
#endif
    return snapshot;
}

static void notifyText(const String& text) {
    if (gloveCharacteristic == nullptr) return;
    gloveCharacteristic->setValue(text.c_str());
    if (deviceConnected) {
        gloveCharacteristic->notify();
    }
}

static void saveDeviceName(const String& nextName) {
    deviceName = nextName.substring(0, MAX_DEVICE_NAME_CHARS);
    prefs.putString("name", deviceName);
    notifyText("OK:" + deviceName);
}

// The name the glove advertises. With a hand set, the side is appended so the
// Android app's name-based hand detection ("...-L" / "...-R") assigns the right
// slot automatically. Capped so the composed name still fits the scan response.
static String advertisedName() {
    if (gloveHand != 'L' && gloveHand != 'R') {
        return deviceName;
    }
    String base = deviceName.substring(0, MAX_DEVICE_NAME_CHARS - 2);
    return base + "-" + String(gloveHand);
}

static void saveHand(char hand) {
    gloveHand = hand; // 0 to clear, or 'L' / 'R'
    prefs.putUChar("hand", static_cast<uint8_t>(gloveHand));
    if (gloveHand == 'L' || gloveHand == 'R') {
        // The advertised name only changes on the next boot (same as NAME:), so
        // tell the app the side is stored and a restart applies it.
        notifyText(String("OK:HAND:") + gloveHand);
    } else {
        notifyText("OK:HAND:CLEAR");
    }
}

// Return the index of the gesture matching `mask`, or -1 if none.
static int findGesture(uint8_t mask) {
    for (int i = 0; i < GESTURE_COUNT; i++) {
        if (GESTURES[i].mask == mask) return i;
    }
    return -1;
}

// Speak a recognised gesture: serial for the PC bridge, BLE for the app, and a
// brief OLED overlay so it's visible on the device too.
static void fireGesture(int gi) {
    Serial.print("SAY:");
    Serial.println(GESTURES[gi].thai);
    notifyText(String("GEST:") + GESTURES[gi].thai);
#if GLOVE_ENABLE_OLED
    strncpy(gestureLabel, GESTURES[gi].en, sizeof(gestureLabel) - 1);
    gestureLabel[sizeof(gestureLabel) - 1] = '\0';
    gestureLabelUntilMs = millis() + 1500;
    lastActivityMs = millis(); // wake the screensaver so the gesture is seen
#endif
}

// Capture the flat-hand reference for gesture detection. Independent of the
// app's telemetry baseline (flexBaseline), so it's safe to re-zero any time.
static void captureGestureBaseline() {
    for (int i = 0; i < FLEX_COUNT; i++) {
        uint32_t total = 0;
        int good = 0;
        for (int s = 0; s < 16; s++) {
            int r = readAnalogAverage(FLEX_PINS[i]);
            if (r >= GESTURE_GLITCH_FLOOR) { total += r; good++; }
            delay(2);
        }
        gestureBaseline[i] = good > 0 ? static_cast<int>(total / good) : 0;
        gestureEma[i] = gestureBaseline[i];
        fingerBent[i] = false;
    }
    gestureEmaReady = true;
    gestureMaskCandidate = 0;
    gestureSpokenMask = 0;
}

// Slowly drift flexBaseline and gestureBaseline toward the current flat-hand
// reading while all fingers are at rest, correcting mechanical hysteresis drift.
static void updateAdaptiveBaseline() {
    if (!gestureEmaReady || flexBaseline[0] == 0) return;

    bool allIdle = true;
    for (int i = 0; i < FLEX_COUNT; i++) {
        int delta = abs(static_cast<int>(lroundf(gestureEma[i])) - gestureBaseline[i]);
        if (delta >= ADAPTIVE_IDLE_THRESHOLD) { allIdle = false; break; }
    }

    uint32_t now = millis();
    if (!allIdle) {
        adaptiveIdleTracking = false;
        return;
    }
    if (!adaptiveIdleTracking) {
        adaptiveIdleSince = now;
        adaptiveIdleTracking = true;
        return;
    }
    if (now - adaptiveIdleSince < ADAPTIVE_IDLE_DURATION_MS) return;

    for (int i = 0; i < FLEX_COUNT; i++) {
        float cur = gestureEma[i];
        flexBaseline[i] = static_cast<uint16_t>(
            lroundf(flexBaseline[i] + ADAPTIVE_BASELINE_ALPHA * (cur - flexBaseline[i]))
        );
        gestureBaseline[i] = static_cast<int>(
            lroundf(gestureBaseline[i] + ADAPTIVE_BASELINE_ALPHA * (cur - gestureBaseline[i]))
        );
    }

    if (now - lastAdaptiveNvsSaveMs >= ADAPTIVE_NVS_SAVE_INTERVAL_MS) {
        for (int i = 0; i < FLEX_COUNT; i++) {
            prefs.putUShort(("z" + String(i)).c_str(), flexBaseline[i]);
        }
        lastAdaptiveNvsSaveMs = now;
    }
}
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
void loop() {
    // Run queued BLE commands here so the BLE stack thread never blocks.
    if (commandPending) {
        String command = pendingCommand;
        commandPending = false;
        processCommand(command);
    }

    if (deviceConnected && streaming && millis() - lastTelemetryMs >= telemetryIntervalMs) {
        lastTelemetryMs = millis();
        latestTelemetry = readTelemetrySnapshot();
        latestTelemetryValid = true;
        telemetryPacketCount++;
        String packet = makeTelemetryPacket(latestTelemetry);
        notifyText(packet);
        Serial.println(packet);
#if GLOVE_ENABLE_OLED
        pushWaveSample(latestTelemetry);
#endif
    }

    if (!deviceConnected && oldDeviceConnected) {
        oldDeviceConnected = deviceConnected;
        advertisingRestartAtMs = millis() + 500;
    }

    if (advertisingRestartAtMs != 0 && millis() >= advertisingRestartAtMs) {
        advertisingRestartAtMs = 0;
        BLEDevice::startAdvertising();
        Serial.println("BLE advertising restarted");
    }

    if (deviceConnected && !oldDeviceConnected) {
        oldDeviceConnected = deviceConnected;
        Serial.println("BLE client connected");
    }

    // Recognise bent-finger gestures and speak them (serial + BLE). Runs every
    // loop regardless of connection; self-rate-limited to GESTURE_SAMPLE_MS.
    updateGestures();

#if GLOVE_ENABLE_OLED
    updateOled();
#endif
}

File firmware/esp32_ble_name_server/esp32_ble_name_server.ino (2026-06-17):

#include <BLE2902.h>
#include <BLEDevice.h>
#include <BLEServer.h>
#include <BLEUtils.h>
#include <Preferences.h>
#include <U8g2lib.h>
#include <Wire.h>

#define SCREEN_WIDTH 128
#define SCREEN_HEIGHT 64

#ifndef I2C_SDA
#if CONFIG_IDF_TARGET_ESP32C3
#define I2C_SDA 5
#define I2C_SCL 6
#else
#endif
#endif

static const char *SERVICE_UUID = "0000FFE0-0000-1000-8000-00805F9B34FB";
static const char *NAME_CHAR_UUID = "0000FFE1-0000-1000-8000-00805F9B34FB";
static const char *NVS_NAMESPACE = "glove";
static const char *NVS_NAME_KEY = "ble_name";
static const char *DEFAULT_NAME = "ESP32 Glove";
static const size_t MAX_NAME_LEN = 20;

Preferences preferences;
BLEServer *server = nullptr;
BLEService *service = nullptr;
BLECharacteristic *nameCharacteristic = nullptr;
BLEAdvertising *advertising = nullptr;
U8G2_SH1106_128X64_NONAME_F_HW_I2C display(U8G2_R0, U8X8_PIN_NONE);

String bleName = DEFAULT_NAME;
String statusText = "BOOTING";
String lastEvent = "Starting BLE";
bool deviceConnected = false;
bool oledReady = false;
uint8_t oledAddress = 0;
unsigned long connectedAtMs = 0;
unsigned long lastDisplayMs = 0;
unsigned long lastEventMs = 0;

void setEvent(const String &event) {
  lastEvent = event;
  lastEventMs = millis();
}

bool probeI2C(uint8_t address) {
  Wire.beginTransmission(address);
  return Wire.endTransmission() == 0;
}

uint8_t findOledAddress() {
  if (probeI2C(0x3C)) {
    return 0x3C;
  }
  if (probeI2C(0x3D)) {
    return 0x3D;
  }
  return 0;
}

void drawText(uint8_t x, uint8_t y, const char *text, uint8_t maxChars) {
  char clipped[32];
  snprintf(clipped, sizeof(clipped), "%s", text);

  if (strlen(clipped) > maxChars) {
    clipped[maxChars] = '\0';
    if (maxChars >= 2) {
      clipped[maxChars - 1] = '.';
      clipped[maxChars - 2] = '.';
    }
  }

  display.drawStr(x, y, clipped);
}

void formatDuration(unsigned long elapsedMs, char *buffer, size_t len) {
  unsigned long totalSeconds = elapsedMs / 1000UL;
  unsigned int hours = totalSeconds / 3600UL;
  unsigned int minutes = (totalSeconds / 60UL) % 60UL;
  unsigned int seconds = totalSeconds % 60UL;
  snprintf(buffer, len, "%02u:%02u:%02u", hours, minutes, seconds);
}

void setupOled() {
  Wire.begin(I2C_SDA, I2C_SCL);
  Wire.setClock(100000);

  oledAddress = findOledAddress();
  if (oledAddress == 0) {
    Serial.println("OLED not found at 0x3C or 0x3D. BLE will run without display.");
    return;
  }

  display.setI2CAddress(oledAddress << 1);
  display.setBusClock(100000);
  display.begin();
  display.clearBuffer();
  display.sendBuffer();
  oledReady = true;

  Serial.print("OLED initialized at 0x");
  Serial.println(oledAddress, HEX);
}

void showBleStatusScreen() {
  if (!oledReady) {
    return;
  }

  char line[32];
  char uptime[12];
  unsigned long elapsedMs = deviceConnected && connectedAtMs > 0
    ? millis() - connectedAtMs
    : millis();

  formatDuration(elapsedMs, uptime, sizeof(uptime));

  display.clearBuffer();
  display.setFont(u8g2_font_6x12_tf);

  display.drawFrame(0, 0, SCREEN_WIDTH, SCREEN_HEIGHT);
  display.drawStr(4, 12, "GLOVE BLE");

  snprintf(line, sizeof(line), "UP %s", uptime);
  display.drawStr(70, 12, line);

  snprintf(line, sizeof(line), "Status:%s", statusText.c_str());
  drawText(4, 27, line, 20);

  snprintf(line, sizeof(line), "Name:%s", bleName.c_str());
  drawText(4, 42, line, 20);

  if (lastEvent.length() > 0 && millis() - lastEventMs < 3000UL) {
    snprintf(line, sizeof(line), "Msg:%s", lastEvent.c_str());
  } else {
    snprintf(line, sizeof(line), "Client:%s", deviceConnected ? "CONNECTED" : "WAITING");
  }
  drawText(4, 57, line, 20);

  display.sendBuffer();
}

void notifyNameResult(const String &message) {
  if (nameCharacteristic == nullptr) {
    return;
  }

  nameCharacteristic->setValue(message.c_str());
  if (deviceConnected) {
    nameCharacteristic->notify();
  }
  nameCharacteristic->setValue(bleName.c_str());
}

String loadBleName() {
  preferences.begin(NVS_NAMESPACE, true);
  String storedName = preferences.getString(NVS_NAME_KEY, DEFAULT_NAME);
  preferences.end();

  storedName.trim();
  if (storedName.length() == 0 || storedName.length() > MAX_NAME_LEN) {
    return DEFAULT_NAME;
  }
  return storedName;
}

bool saveBleName(const String &newName) {
  preferences.begin(NVS_NAMESPACE, false);
  size_t written = preferences.putString(NVS_NAME_KEY, newName);
  preferences.end();
  return written > 0;
}

void startAdvertising() {
  if (advertising == nullptr) {
    return;
  }

  BLEAdvertisementData advertisementData;
  advertisementData.setFlags(ESP_BLE_ADV_FLAG_GEN_DISC | ESP_BLE_ADV_FLAG_BREDR_NOT_SPT);
  advertisementData.setCompleteServices(BLEUUID(SERVICE_UUID));

  BLEAdvertisementData scanResponseData;
  scanResponseData.setName(bleName);

  advertising->stop();
  advertising->setScanResponse(true);
  advertising->setAdvertisementData(advertisementData);
  advertising->setScanResponseData(scanResponseData);
  advertising->start();
  statusText = "ADVERTISING";
  setEvent("Ready");

  Serial.print("Advertising as ");
  Serial.println(bleName);
}

class ServerCallbacks : public BLEServerCallbacks {
  void onConnect(BLEServer *server) override {
    deviceConnected = true;
    connectedAtMs = millis();
    statusText = "CONNECTED";
    setEvent("Phone OK");
    Serial.println("BLE client connected");
  }

  void onDisconnect(BLEServer *server) override {
    deviceConnected = false;
    connectedAtMs = 0;
    statusText = "DISCONNECTED";
    setEvent("Lost link");
    Serial.println("BLE client disconnected");
    delay(100);
    startAdvertising();
    setEvent("Lost link");
  }
};

class NameCharacteristicCallbacks : public BLECharacteristicCallbacks {
  void onWrite(BLECharacteristic *characteristic) override {
    String newName = String(characteristic->getValue().c_str());
    newName.trim();

    Serial.print("Name write request: ");
    Serial.println(newName);

    if (newName.length() == 0) {
      setEvent("Name empty");
      notifyNameResult("ERR:Empty name");
      return;
    }

    if (newName.length() > MAX_NAME_LEN) {
      setEvent("Name long");
      notifyNameResult("ERR:Name too long");
      return;
    }

    if (!saveBleName(newName)) {
      setEvent("NVS error");
      notifyNameResult("ERR:NVS save failed");
      return;
    }

    bleName = newName;
    nameCharacteristic->setValue(bleName.c_str());
    setEvent("Name saved");
    notifyNameResult("OK:" + bleName);

    Serial.print("Saved BLE name: ");
    Serial.println(bleName);
  }

  void onRead(BLECharacteristic *characteristic) override {
    characteristic->setValue(bleName.c_str());
  }
};
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

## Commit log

2026-06-19 rst commit
    [base.stl, lid.3mf, lid.stl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]
2026-06-26 st commit
    [base.3mf, base.stl, bom_budget.ods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]
2026-06-27 fiuc commit
    [base.3mf, base.stl, full.3mf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]
2026-06-28 fix Android 13 BLE connection and scan issues
    - Move discoverServices() into onMtuChanged callback to fix GATT error 133
    on Android 13 caused by overlapping MTU exchange and service discovery on
    the ATT channel
    - Fix scan filter dropping unpaired devices whose name is null on Android 13;
    devices advertising the glove service UUID now get a fallback name instead
    of being silently discarded
    - Configure Gradle to use the installed Java 25 JDK toolchain
    - Firmware: add adaptive flex baseline to correct sensor drift over time (v2.3.0)
    [esp32_glove_ble.ino]
